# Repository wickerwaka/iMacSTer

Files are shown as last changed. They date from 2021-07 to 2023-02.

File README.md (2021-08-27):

# iMacSTer
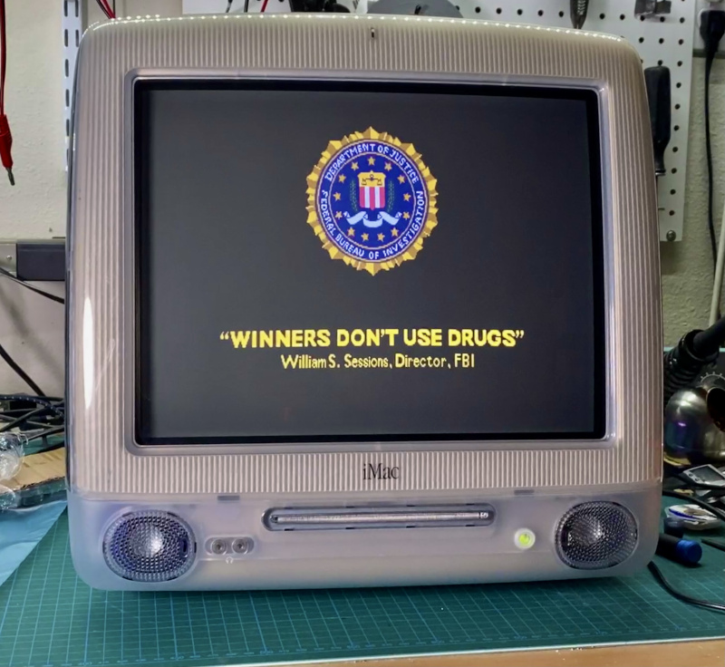
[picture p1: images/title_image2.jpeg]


The iMacSTer is an early 2000's Apple iMac G3 with a MiSTer FPGA multisystem emulator inside of it. It is intended to be a non-destructive modification so the iMac can be returned to it's original state if desired. The mainboard, drives and IO panel are removed and replace by custom hardware, but no cuts are made to the chassis and the new hardware connects to existing internal connections without the need for any soldering. That being said, I can make no guarantees about the long term implications of these modifications. The speakers are being driven by a different amplifier than they were intended for, the new hardware only uses the 5V output from a power supply which is expecting load on the 3.3V and 12V lines also, the monitor is being driven at a resolution higher than it was intended for, heat generation and dissipation characteristics have changed, etc, etc.

## Past Work
None of this would be possible without the work of Rocky Hill and others to reverse engineer the iMac internals and design custom hardware and software to interface with it. I would not have attempted this project if the [imac_g3_ivad_board_init](https://github.com/qbancoffee/imac_g3_ivad_board_init) project did not exist. My PCBs and software is all based on that work and I still use the down converter adaptor board from that project because there was no need to change it.

I also used the IO shield designs that @Diepzeevogel created as part of their [replacement parts project](https://github.com/Diepzeevogel/iMac-G3-replacement-parts) as the basis for my own IO shield. The fit and quality that they were able to achieve is beyond my own skills.

## Features
 * 2W x 2 Stereo amplifier
 * Dual headphone ports for two player fun
 * External volume control
 * 4 external USB ports
 * Built-in WiFi
 * Access to all MiSTer buttons and OSD
 * Sleek design for any modern home

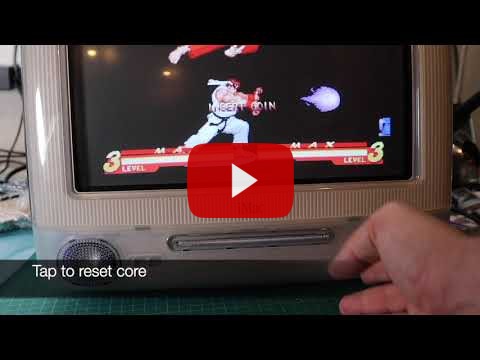
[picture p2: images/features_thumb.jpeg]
Features Video (https://www.youtube.com/watch?v=8O5fEVcCo0Q)


[Other Random Photos](https://photos.app.goo.gl/XmcNqWLyWzHymW5z9)

## Assembly
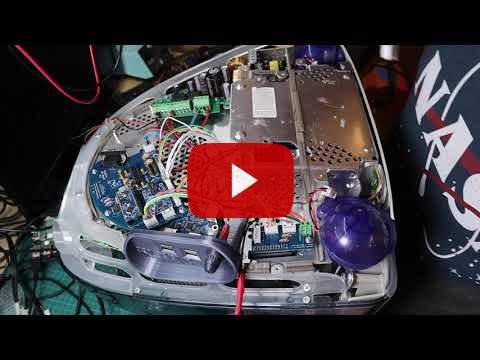
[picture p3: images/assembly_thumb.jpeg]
Assembly Video (https://www.youtube.com/watch?v=OmDPnWWWzPM)


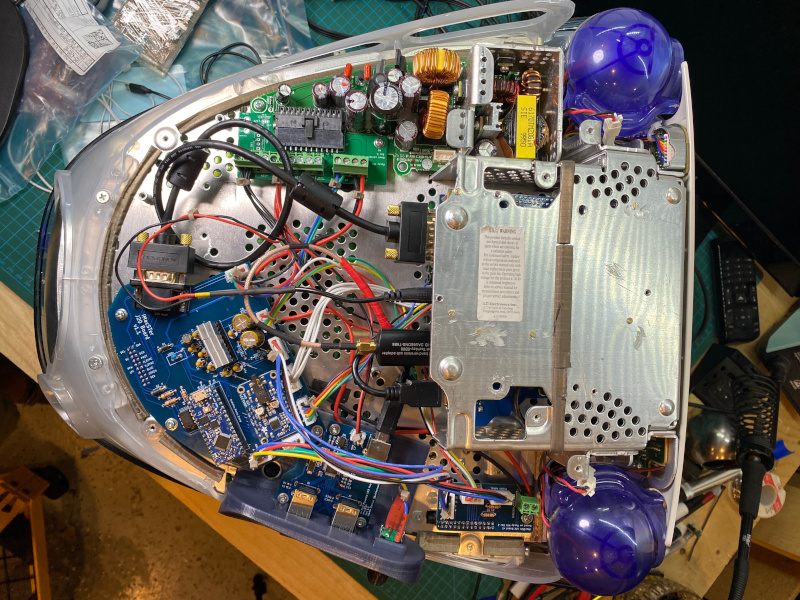
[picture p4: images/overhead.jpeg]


## Main Board
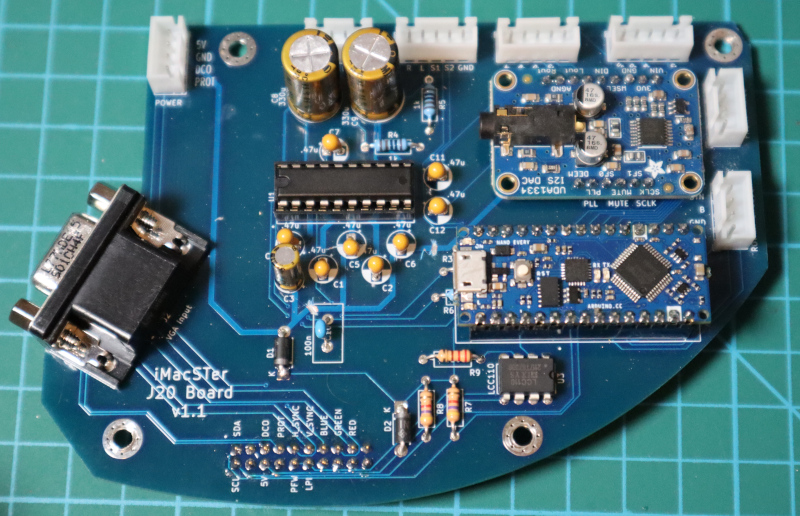
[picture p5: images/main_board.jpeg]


The main board controls the whole system. It contains an I2S digital-to-analog audio converter, an audio amplifier and an Arduino Nano Every for controlling everything. It connects to the J20 connector inside the iMac which provides 5V to the microcontroller even when the system is powered down. The J20 port is also where the VGA signals are from the VGA connector on the board.

The amplifier is a Texas Instruments [TPA6021A4](https://www.ti.com/lit/ds/symlink/tpa6021a4.pdf) 2W Stereo amplifier. I picked this one because it was in the power range I needed, it supported a headphone mode, the volume level could be controlled by a microcontroller and it came in a through-hole package. That last point really limits the options since most amplifier ICs with similar features come in surface mount packages. When I started this project I had no experience designing PCBs or using surface mount components, so I was limiting myself to through-hole parts. The decoupling, biasing and filtering capacitors in the amplifier section are all directly copied from the reference schematics in the datasheet, with the exception of the output capacitors which I switch from 330uF to 2200uF in order to get more bass.

The amplifier output is connected to the speakers and headphones via two JST connectors. The iMac has two separate headphone ports on the front and each has their own headphone sense signal. These signals need to be OR'd together to determine whether the amplifier should be in single ended (headphone) mode or not. This is done by the arduino rather than a separate IC, which has the added advantage of allowing separate volume settings for speaker and headphone mode.

The audio input to the amplifier comes from the [UDA1334A](https://cdn-shop.adafruit.com/product-files/3678/UDA1334ATS.pdf) [breakout board](https://www.adafruit.com/product/3678) from Adafruit. The UDA1334A decodes the I2S audio data from the MiSTer and converts it to an analog signal. I had assumed the output capacitors on the breakout board would block DC into the amplifier so an earlier version of the board did not have any capacitors protecting the input. That assumption cost me a pair of speakers, they literally ripped themselves apart.

The arduino controls the system power, the CRT configuration, the amplifier, the buttons and LEDs on the case and the three standard buttons on the MiSTer. I considered using an ATmega microcontroller directly instead of the Nano Every, however the Nano packs a lot of features into a small space. I want the convenience of a USB port without having to worry about whether I've hooked it all up correctly. 

iMac video hardware requires a special initialization sequence to be sent via I2C before it will power on the CRT and start displaying an image ([much more detailed explaination here](https://github.com/qbancoffee/imac_g3_ivad_board_init/wiki/Convert-and-iMac-G3-slot-loader-into-a-standard-VGA-monitor)). The I2C connection is also used to configure display properties like brightness and alignment. These settings are stored in EEPROM and can be modified using serial commands.

## USB Hubs
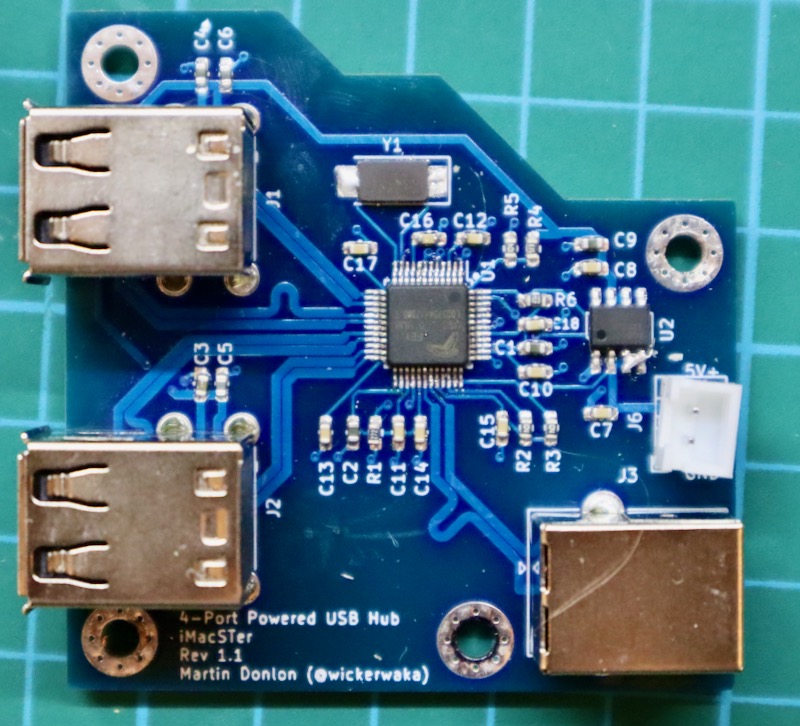
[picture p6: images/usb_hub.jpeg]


There are two USB hubs inside, one is used for internal connections and one is mounted on the IO shield for external connections. The hub is based on the [FE1.1](https://elinux.org/images/e/ee/FE11-datasheet.pdf) chip which does pretty much everything. Building my own USB hubs is not something I considered doing at the start of this project, I had never designed a PCB and I had never used surface mount components. I had deliberately avoided surface mount components when picking an amplifier for the main board. This seemed achievable though and I had watched enough videos at this point to not be terrified of surface mount soldering. It was pretty surprising when it worked!

The hub includes a current-limited switch, but I have not been able to get the power control from the FE1.1 to work correctly. For now it is latched one with a blob of solder. There is still some current limiting due to the thermal shutoff building into the switch, but it is not going to be reported to the hub correctly.

## MiSTer
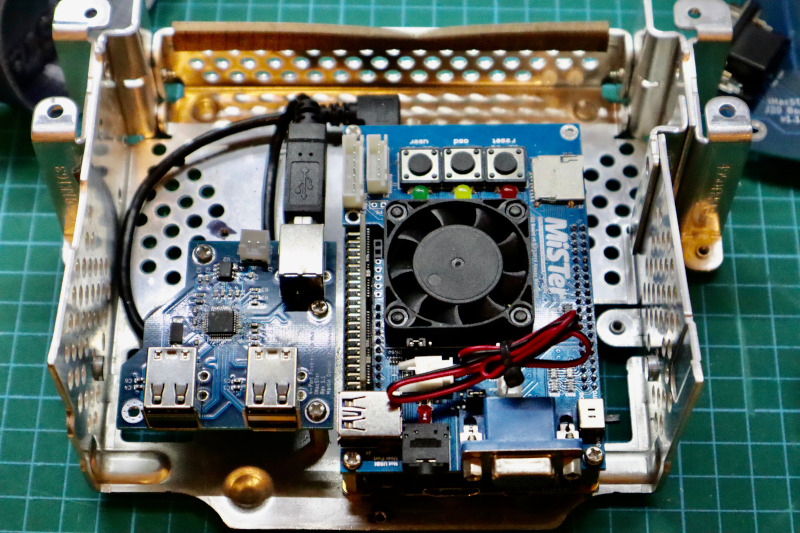
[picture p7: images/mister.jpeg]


The [MiSTer](https://github.com/MiSTer-devel/Main_MiSTer/wiki) setup is the standard combo of DE-10 Nano, 128MB SDRAM and the analog IO board. The 5-pin button and I2S headers are connected to the matching headers on the main board. The MiSTer is mounted in the drive bay alongside one of the USB hubs. I drilled and tapped holes in the drive bay to allow both of them to be mounted. This is a destructive modification, though it is not externally visible and does not impact the functionality of the drive bay if the original drives ever needed to be added back in.

## Power and Front Panel
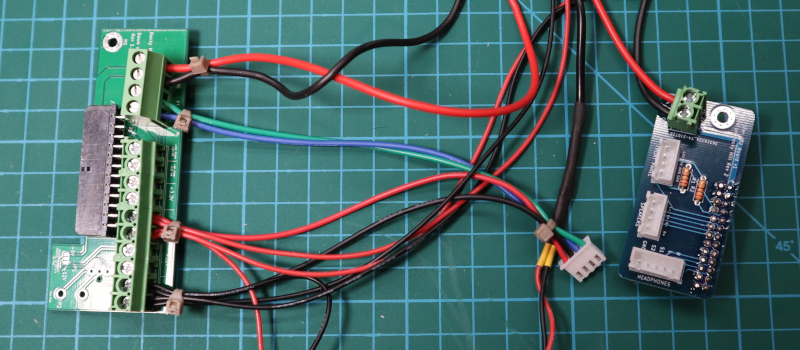
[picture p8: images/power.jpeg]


The power for the system comes from the J22 connector as 24VAC. This 24VAC is feed into the down converter board which outputs 12V, 5V and 3.3V DC. The 5V output is used to power everything else in the system. The J22 connector also has connections for the speakers, headphones, power button and it's LEDs. This are all exposed through three JST connectors on the adaptor board.

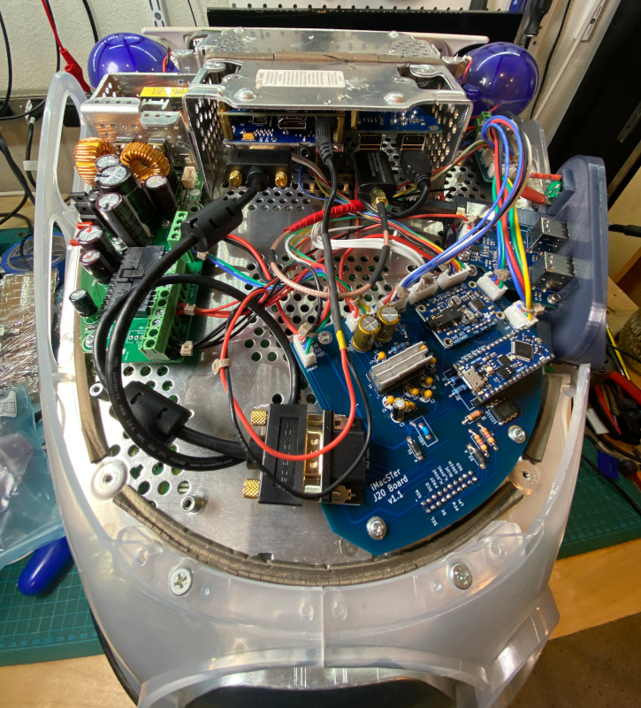
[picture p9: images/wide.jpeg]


## IO Shield
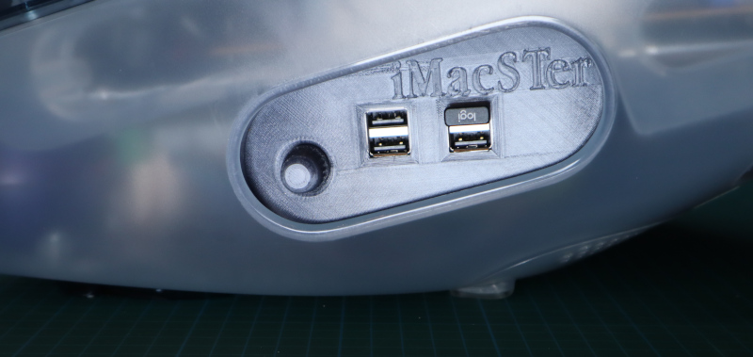
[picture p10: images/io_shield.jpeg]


The IO shield provides a mounting point for the external USB hub and the rotary encoder. Thanks to the work [here](https://github.com/Diepzeevogel/iMac-G3-replacement-parts) it matches the curves of the case very closely. It is 3D printed using eSUN's Semi-transparent Gray PETG filament which matches well with the "Graphite" color of this iMac.

The metal plate that the IO shield is attached to has a lot of holes so finding suitable attachment points was not difficult. However getting access to the other side of that metal plate is extremely difficult so I opted to build in some plugs that expand when a bolt is screwed into them, similar to dry wall screws. 

## Video Modes
The CRT in the iMac is limited to a horizontal sync of 57-63KHz. The only mode suitable for 60Hz refresh rate is 1280x960. At this resolution the horizontal refresh rate is 1000x the vertical rate so when using `vsync_adjust` the vertical rate can be adjusted from 57-63Hz, which gives good coverage for NTSC and most arcade systems. The brightness and alignment of the screen does change across that frequency range, so at the extremes the picture will be slightly distorted. A future version of the board may sample the hsync signal and adjust the video settings based on it.

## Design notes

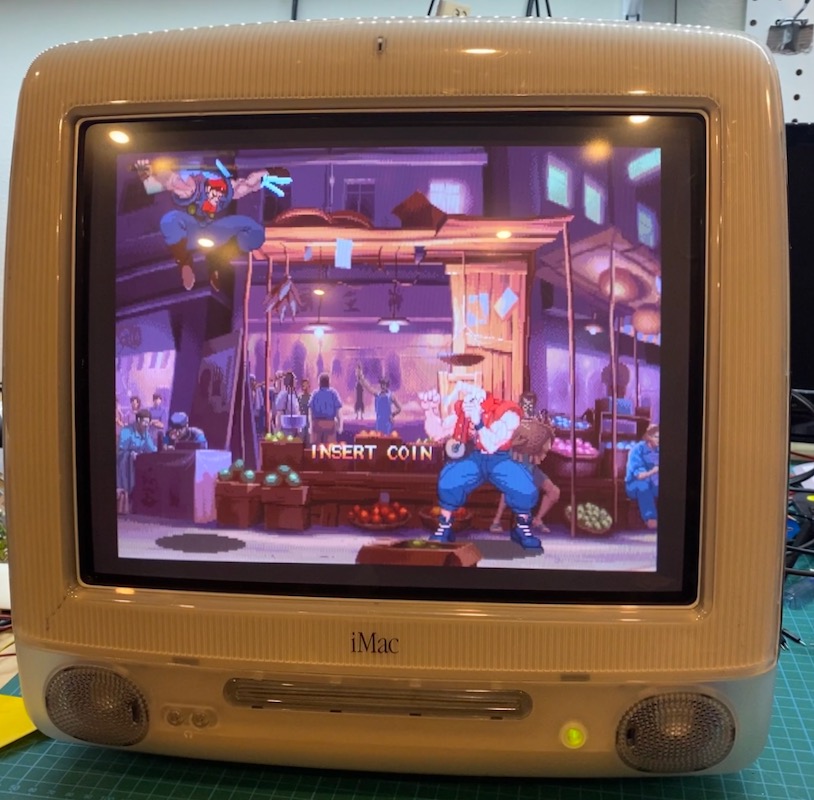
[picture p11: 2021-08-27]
images/title_image.jpeg

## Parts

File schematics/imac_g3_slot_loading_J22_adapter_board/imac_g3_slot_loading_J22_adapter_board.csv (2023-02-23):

Source: | C:\Users\Martin\Source\iMacSTer\schematics\imac_g3_slot_loading_J22_adapter_board\imac_g3_slot_loading_J22_adapter_board.kicad_sch
Date: | 2/22/2023 10:14:35 PM
Tool: | Eeschema (6.0.5)
Generator: | C:\Program Files\KiCad\6.0\bin\scripting\plugins/bom_csv_grouped_by_value.py
Component Count: | 8
Individual Components:
Item | Qty | Reference(s) | Value | LibPart | Footprint | Datasheet | Part# | Vendor
 |  | H1 | MountingHole_Pad | Mechanical:MountingHole_Pad | MountingHole:MountingHole_3.5mm_Pad_Via | ~
 |  | J1 | Conn_02x13_Odd_Even | Connector_Generic:Conn_02x13_Odd_Even | Connector_PinHeader_2.54mm:PinHeader_2x13_P2.54mm_Vertical | https://cdn.amphenol-icc.com/media/wysiwyg/files/drawing/67996.pdf | 3M156308-26-ND | digikey
 |  | J2 | AC Power | Connector:Screw_Terminal_01x02 | TerminalBlock_Phoenix:TerminalBlock_Phoenix_PT-1,5-2-5.0-H_1x02_P5.00mm_Horizontal | https://www.phoenixcontact.com/pxc-oc-itemdetail-pdf-web/eshop?lineItemType=LineItem&UID=1935857 | 277-6405-ND | digikey
 |  | J3 | Conn_01x04_Male | Connector:Conn_01x04_Male | Connector_JST:JST_XH_B4B-XH-A_1x04_P2.50mm_Vertical | ~ | 455-2249-ND | digikey
 |  | J4 | Conn_01x04_Male | Connector:Conn_01x04_Male | Connector_JST:JST_XH_B4B-XH-A_1x04_P2.50mm_Vertical | ~ | 455-2249-ND | digikey
 |  | J5 | Conn_01x04_Male | Connector:Conn_01x05_Male | Connector_JST:JST_XH_B5B-XH-A_1x05_P2.50mm_Vertical | ~ | 455-2270-ND | digikey
 |  | R1 | 220 | Device:R_Small_US | Resistor_THT:R_Axial_DIN0207_L6.3mm_D2.5mm_P7.62mm_Horizontal | https://www.seielect.com/catalog/sei-cf_cfm.pdf | CF14JT220RCT-ND | digikey
 |  | R2 | 220 | Device:R_Small_US | Resistor_THT:R_Axial_DIN0207_L6.3mm_D2.5mm_P7.62mm_Horizontal | https://www.seielect.com/catalog/sei-cf_cfm.pdf | CF14JT220RCT-ND | digikey
Collated Components:
Item | Qty | Reference(s) | Value | LibPart | Footprint | Datasheet | Part# | Vendor
1 | 1 | H1 | MountingHole_Pad | Mechanical:MountingHole_Pad | MountingHole:MountingHole_3.5mm_Pad_Via | ~
2 | 1 | J1 | Conn_02x13_Odd_Even | Connector_Generic:Conn_02x13_Odd_Even | Connector_PinHeader_2.54mm:PinHeader_2x13_P2.54mm_Vertical | https://cdn.amphenol-icc.com/media/wysiwyg/files/drawing/67996.pdf | 3M156308-26-ND | digikey
3 | 1 | J2 | AC Power | Connector:Screw_Terminal_01x02 | TerminalBlock_Phoenix:TerminalBlock_Phoenix_PT-1,5-2-5.0-H_1x02_P5.00mm_Horizontal | https://www.phoenixcontact.com/pxc-oc-itemdetail-pdf-web/eshop?lineItemType=LineItem&UID=1935857 | 277-6405-ND | digikey
4 | 2 | J3, J4 | Conn_01x04_Male | Connector:Conn_01x04_Male | Connector_JST:JST_XH_B4B-XH-A_1x04_P2.50mm_Vertical | ~ | 455-2249-ND | digikey
5 | 1 | J5 | Conn_01x04_Male | Connector:Conn_01x05_Male | Connector_JST:JST_XH_B5B-XH-A_1x05_P2.50mm_Vertical | ~ | 455-2270-ND | digikey
6 | 2 | R1, R2 | 220 | Device:R_Small_US | Resistor_THT:R_Axial_DIN0207_L6.3mm_D2.5mm_P7.62mm_Horizontal | https://www.seielect.com/catalog/sei-cf_cfm.pdf | CF14JT220RCT-ND | digikey

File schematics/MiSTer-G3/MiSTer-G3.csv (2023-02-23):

Source: | C:\Users\Martin\Source\iMacSTer\schematics\MiSTer-G3\MiSTer-G3.kicad_sch
Date: | 2/22/2023 10:15:50 PM
Tool: | Eeschema (6.0.5)
Generator: | C:\Program Files\KiCad\6.0\bin\scripting\plugins/bom_csv_grouped_by_value.py
Component Count: | 42
Individual Components:
Item | Qty | Reference(s) | Value | LibPart | Footprint | Datasheet | Part# | Vendor
 |  | A1 | Arduino_Nano_Every | MCU_Module:Arduino_Nano_Every | Module:Arduino_Nano | https://content.arduino.cc/assets/NANOEveryV3.0_sch.pdf | S7013-ND | digikey
 |  | C1 | .47u | MiSTer-G3-rescue:CP1-Device | Capacitor_THT:CP_Radial_D5.0mm_P2.50mm |  | 478-8779-1-ND | digikey
 |  | C2 | .47u | MiSTer-G3-rescue:CP1-Device | Capacitor_THT:CP_Radial_D5.0mm_P2.50mm |  | 478-8779-1-ND | digikey
 |  | C3 | 10u | MiSTer-G3-rescue:CP1-Device | Capacitor_THT:CP_Radial_D5.0mm_P2.00mm |  | 493-15134-ND | digikey
 |  | C4 | .47u | MiSTer-G3-rescue:CP1-Device | Capacitor_THT:CP_Radial_D5.0mm_P2.50mm |  | 478-8779-1-ND | digikey
 |  | C5 | .47u | MiSTer-G3-rescue:CP1-Device | Capacitor_THT:CP_Radial_D5.0mm_P2.50mm |  | 478-8779-1-ND | digikey
 |  | C6 | .47u | MiSTer-G3-rescue:CP1-Device | Capacitor_THT:CP_Radial_D5.0mm_P2.50mm |  | 478-8779-1-ND | digikey
 |  | C7 | .47u | MiSTer-G3-rescue:CP1-Device | Capacitor_THT:CP_Radial_D5.0mm_P2.50mm |  | 478-8779-1-ND | digikey
 |  | C8 | 330u | MiSTer-G3-rescue:CP1-Device | Capacitor_THT:CP_Radial_D10.0mm_P5.00mm |  | 493-3180-ND | digikey
 |  | C9 | 330u | MiSTer-G3-rescue:CP1-Device | Capacitor_THT:CP_Radial_D10.0mm_P5.00mm |  | 493-3180-ND | digikey
 |  | C10 | 100n | Device:C_Small | Capacitor_THT:C_Disc_D10.5mm_W5.0mm_P5.00mm | ~ | 445-173588-1-ND | digikey
 |  | C11 | .47u | MiSTer-G3-rescue:CP1-Device | Capacitor_THT:CP_Radial_D5.0mm_P2.00mm |  | 478-8779-1-ND | digikey
 |  | C12 | .47u | MiSTer-G3-rescue:CP1-Device | Capacitor_THT:CP_Radial_D5.0mm_P2.00mm |  | 478-8779-1-ND | digikey
 |  | D1 | D_Schottky_ALT | MiSTer-G3-rescue:D_Schottky_ALT-Device | Diode_THT:D_DO-41_SOD81_P7.62mm_Horizontal |  | 1N5819-E3/54GICT-ND | digikey
 |  | D2 | D_Schottky_ALT | MiSTer-G3-rescue:D_Schottky_ALT-Device | Diode_THT:D_DO-41_SOD81_P7.62mm_Horizontal |  | 1N5819-E3/54GICT-ND | digikey
 |  | H1 | MountingHole_Pad | Mechanical:MountingHole_Pad | MountingHole:MountingHole_3.5mm_Pad_Via | ~
 |  | H2 | MountingHole_Pad | Mechanical:MountingHole_Pad | MountingHole:MountingHole_3.5mm_Pad_Via | ~
 |  | H3 | MountingHole_Pad | Mechanical:MountingHole_Pad | MountingHole:MountingHole_3.5mm_Pad_Via | ~
 |  | H4 | MountingHole_Pad | Mechanical:MountingHole_Pad | MountingHole:MountingHole_3.5mm_Pad_Via | ~
 |  | J1 | Apple J20 | Connector_Generic:Conn_02x10_Odd_Even | Connector_PinHeader_2.54mm:PinHeader_2x10_P2.54mm_Vertical | ~ | SAM1068-10-ND | digikey
 |  | J2 | VGA Input | Connector:DB15_Female_HighDensity | Connector_Dsub:DSUB-15-HD_Female_Horizontal_P2.29x1.98mm_EdgePinOffset8.35mm_Housed_MountingHolesOffset10.89mm | ~ | L77HDE15SD1CH4F-ND | digikey
 |  | J3 | Speaker | Connector:Conn_01x04_Male | Connector_JST:JST_XH_B4B-XH-A_1x04_P2.50mm_Vertical | ~ | 455-2249-ND | digikey
 |  | J4 | I2S | Connector:Conn_01x05_Male | Connector_JST:JST_XH_B5B-XH-A_1x05_P2.50mm_Vertical | ~ | 455-2270-ND | digikey
 |  | J5 | Power | Connector:Conn_01x04_Male | Connector_JST:JST_XH_B4B-XH-A_1x04_P2.50mm_Vertical | ~ | 455-2249-ND | digikey
 |  | J6 | Rotary Encoder | Connector:Conn_01x04_Male | Connector_JST:JST_XH_B4B-XH-A_1x04_P2.50mm_Vertical | ~ | 455-2249-ND | digikey
 |  | J7 | Headphones | Connector:Conn_01x05_Male | Connector_JST:JST_XH_B5B-XH-A_1x05_P2.50mm_Vertical | ~ | 455-2270-ND | digikey
 |  | J8 | Front Panel | Connector:Conn_01x04_Male | Connector_JST:JST_XH_B4B-XH-A_1x04_P2.50mm_Vertical | ~ | 455-2249-ND | digikey
 |  | J9 | Buttons | Connector:Conn_01x05_Male | Connector_JST:JST_XH_B5B-XH-A_1x05_P2.50mm_Vertical | ~ | 455-2270-ND | digikey
 |  | R1 | 100k | Device:R | Resistor_THT:R_Axial_DIN0207_L6.3mm_D2.5mm_P10.16mm_Horizontal | ~ | 100KQBK-ND | digikey
 |  | R2 | 100k | Device:R | Resistor_THT:R_Axial_DIN0207_L6.3mm_D2.5mm_P10.16mm_Horizontal | ~ | 100KQBK-ND | digikey
 |  | R3 | 10k | Device:R | Resistor_THT:R_Axial_DIN0207_L6.3mm_D2.5mm_P10.16mm_Horizontal | ~ | 10KQBK-ND | digikey
 |  | R4 | 1k | Device:R | Resistor_THT:R_Axial_DIN0207_L6.3mm_D2.5mm_P10.16mm_Horizontal | ~ | 1.0KQBK-ND | digikey
 |  | R5 | 1k | Device:R | Resistor_THT:R_Axial_DIN0207_L6.3mm_D2.5mm_P10.16mm_Horizontal | ~ | 1.0KQBK-ND | digikey
 |  | R6 | 10k | Device:R_Small | Resistor_THT:R_Axial_DIN0207_L6.3mm_D2.5mm_P10.16mm_Horizontal | ~ | 10KQBK-ND | digikey
 |  | R7 | 4.7k | Device:R_Small | Resistor_THT:R_Axial_DIN0207_L6.3mm_D2.5mm_P10.16mm_Horizontal | ~ | 4.7KQBK-ND | digikey
 |  | R8 | 4.7k | Device:R_Small | Resistor_THT:R_Axial_DIN0207_L6.3mm_D2.5mm_P10.16mm_Horizontal | ~ | 4.7KQBK-ND | digikey
 |  | R9 | 220 | Device:R_Small | Resistor_THT:R_Axial_DIN0207_L6.3mm_D2.5mm_P10.16mm_Horizontal | ~ | 220QBK-ND | digikey
 |  | R10 | 100k | Device:R | Resistor_THT:R_Axial_DIN0207_L6.3mm_D2.5mm_P10.16mm_Horizontal | ~ | 100KQBK-ND | digikey
 |  | R11 | 100k | Device:R | Resistor_THT:R_Axial_DIN0207_L6.3mm_D2.5mm_P10.16mm_Horizontal | ~ | 100KQBK-ND | digikey
 |  | U1 | TPA6021A4N | MiSTer-Custom:TPA6021A4N | MiSTer-G3:TPA6021A4 |  | 296-18249-5-ND | digikey
 |  | U2 | UDA1334A | MiSTer-Custom:UDA1334A | MiSTer-G3:UDA1334_Breakout |  | 3678 | adafruit
 |  | U3 | LCC110 | Relay_SolidState:LCC110 | Package_DIP:DIP-8_W7.62mm | http://www.ixysic.com/home/pdfs.nsf/www/LCC110.pdf/$file/LCC110.pdf | CLA106-ND | digikey
Collated Components:
Item | Qty | Reference(s) | Value | LibPart | Footprint | Datasheet | Part# | Vendor
1 | 1 | A1 | Arduino_Nano_Every | MCU_Module:Arduino_Nano_Every | Module:Arduino_Nano | https://content.arduino.cc/assets/NANOEveryV3.0_sch.pdf | S7013-ND | digikey
2 | 6 | C1, C2, C4, C5, C6, C7 | .47u | MiSTer-G3-rescue:CP1-Device | Capacitor_THT:CP_Radial_D5.0mm_P2.50mm |  | 478-8779-1-ND | digikey
3 | 1 | C3 | 10u | MiSTer-G3-rescue:CP1-Device | Capacitor_THT:CP_Radial_D5.0mm_P2.00mm |  | 493-15134-ND | digikey
4 | 2 | C8, C9 | 330u | MiSTer-G3-rescue:CP1-Device | Capacitor_THT:CP_Radial_D10.0mm_P5.00mm |  | 493-3180-ND | digikey
5 | 1 | C10 | 100n | Device:C_Small | Capacitor_THT:C_Disc_D10.5mm_W5.0mm_P5.00mm | ~ | 445-173588-1-ND | digikey
6 | 2 | C11, C12 | .47u | MiSTer-G3-rescue:CP1-Device | Capacitor_THT:CP_Radial_D5.0mm_P2.00mm |  | 478-8779-1-ND | digikey
7 | 2 | D1, D2 | D_Schottky_ALT | MiSTer-G3-rescue:D_Schottky_ALT-Device | Diode_THT:D_DO-41_SOD81_P7.62mm_Horizontal |  | 1N5819-E3/54GICT-ND | digikey
8 | 4 | H1, H2, H3, H4 | MountingHole_Pad | Mechanical:MountingHole_Pad | MountingHole:MountingHole_3.5mm_Pad_Via | ~
9 | 1 | J1 | Apple J20 | Connector_Generic:Conn_02x10_Odd_Even | Connector_PinHeader_2.54mm:PinHeader_2x10_P2.54mm_Vertical | ~ | SAM1068-10-ND | digikey
10 | 1 | J2 | VGA Input | Connector:DB15_Female_HighDensity | Connector_Dsub:DSUB-15-HD_Female_Horizontal_P2.29x1.98mm_EdgePinOffset8.35mm_Housed_MountingHolesOffset10.89mm | ~ | L77HDE15SD1CH4F-ND | digikey
11 | 1 | J3 | Speaker | Connector:Conn_01x04_Male | Connector_JST:JST_XH_B4B-XH-A_1x04_P2.50mm_Vertical | ~ | 455-2249-ND | digikey
12 | 1 | J4 | I2S | Connector:Conn_01x05_Male | Connector_JST:JST_XH_B5B-XH-A_1x05_P2.50mm_Vertical | ~ | 455-2270-ND | digikey
13 | 1 | J5 | Power | Connector:Conn_01x04_Male | Connector_JST:JST_XH_B4B-XH-A_1x04_P2.50mm_Vertical | ~ | 455-2249-ND | digikey
14 | 1 | J6 | Rotary Encoder | Connector:Conn_01x04_Male | Connector_JST:JST_XH_B4B-XH-A_1x04_P2.50mm_Vertical | ~ | 455-2249-ND | digikey
15 | 1 | J7 | Headphones | Connector:Conn_01x05_Male | Connector_JST:JST_XH_B5B-XH-A_1x05_P2.50mm_Vertical | ~ | 455-2270-ND | digikey
16 | 1 | J8 | Front Panel | Connector:Conn_01x04_Male | Connector_JST:JST_XH_B4B-XH-A_1x04_P2.50mm_Vertical | ~ | 455-2249-ND | digikey
17 | 1 | J9 | Buttons | Connector:Conn_01x05_Male | Connector_JST:JST_XH_B5B-XH-A_1x05_P2.50mm_Vertical | ~ | 455-2270-ND | digikey
18 | 4 | R1, R2, R10, R11 | 100k | Device:R | Resistor_THT:R_Axial_DIN0207_L6.3mm_D2.5mm_P10.16mm_Horizontal | ~ | 100KQBK-ND | digikey
19 | 1 | R3 | 10k | Device:R | Resistor_THT:R_Axial_DIN0207_L6.3mm_D2.5mm_P10.16mm_Horizontal | ~ | 10KQBK-ND | digikey
20 | 2 | R4, R5 | 1k | Device:R | Resistor_THT:R_Axial_DIN0207_L6.3mm_D2.5mm_P10.16mm_Horizontal | ~ | 1.0KQBK-ND | digikey
21 | 1 | R6 | 10k | Device:R_Small | Resistor_THT:R_Axial_DIN0207_L6.3mm_D2.5mm_P10.16mm_Horizontal | ~ | 10KQBK-ND | digikey
22 | 2 | R7, R8 | 4.7k | Device:R_Small | Resistor_THT:R_Axial_DIN0207_L6.3mm_D2.5mm_P10.16mm_Horizontal | ~ | 4.7KQBK-ND | digikey
23 | 1 | R9 | 220 | Device:R_Small | Resistor_THT:R_Axial_DIN0207_L6.3mm_D2.5mm_P10.16mm_Horizontal | ~ | 220QBK-ND | digikey
24 | 1 | U1 | TPA6021A4N | MiSTer-Custom:TPA6021A4N | MiSTer-G3:TPA6021A4 |  | 296-18249-5-ND | digikey
25 | 1 | U2 | UDA1334A | MiSTer-Custom:UDA1334A | MiSTer-G3:UDA1334_Breakout |  | 3678 | adafruit
26 | 1 | U3 | LCC110 | Relay_SolidState:LCC110 | Package_DIP:DIP-8_W7.62mm | http://www.ixysic.com/home/pdfs.nsf/www/LCC110.pdf/$file/LCC110.pdf | CLA106-ND | digikey

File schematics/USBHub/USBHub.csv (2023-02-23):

Source: | C:\Users\Martin\Source\iMacSTer\schematics\USBHub\USBHub.kicad_sch
Date: | 2/22/2023 10:15:37 PM
Tool: | Eeschema (6.0.5)
Generator: | C:\Program Files\KiCad\6.0\bin\scripting\plugins/bom_csv_grouped_by_value.py
Component Count: | 35
Individual Components:
Item | Qty | Reference(s) | Value | LibPart | Footprint | Datasheet | Part# | Vendor
 |  | C1 | 10u | Device:C_Small | Capacitor_SMD:C_0603_1608Metric_Pad1.08x0.95mm_HandSolder | ~ | 1276-1038-1-ND | digikey
 |  | C2 | 10u | Device:C_Small | Capacitor_SMD:C_0603_1608Metric_Pad1.08x0.95mm_HandSolder | ~ | 1276-1038-1-ND | digikey
 |  | C3 | 10u | Device:C_Small | Capacitor_SMD:C_0603_1608Metric_Pad1.08x0.95mm_HandSolder | ~ | 1276-1038-1-ND | digikey
 |  | C4 | 10u | Device:C_Small | Capacitor_SMD:C_0603_1608Metric_Pad1.08x0.95mm_HandSolder | ~ | 1276-1038-1-ND | digikey
 |  | C5 | 10u | Device:C_Small | Capacitor_SMD:C_0603_1608Metric_Pad1.08x0.95mm_HandSolder | ~ | 1276-1038-1-ND | digikey
 |  | C6 | 10u | Device:C_Small | Capacitor_SMD:C_0603_1608Metric_Pad1.08x0.95mm_HandSolder | ~ | 1276-1038-1-ND | digikey
 |  | C7 | 100n | Device:C_Small | Capacitor_SMD:C_0603_1608Metric_Pad1.08x0.95mm_HandSolder | ~ | 1276-1935-1-ND | digikey
 |  | C8 | 100n | Device:C_Small | Capacitor_SMD:C_0603_1608Metric_Pad1.08x0.95mm_HandSolder | ~ | 1276-1935-1-ND | digikey
 |  | C9 | 10u | Device:C_Small | Capacitor_SMD:C_0603_1608Metric_Pad1.08x0.95mm_HandSolder | ~ | 1276-1038-1-ND | digikey
 |  | C10 | 100n | Device:C_Small | Capacitor_SMD:C_0603_1608Metric_Pad1.08x0.95mm_HandSolder | ~ | 1276-1935-1-ND | digikey
 |  | C11 | 100n | Device:C_Small | Capacitor_SMD:C_0603_1608Metric_Pad1.08x0.95mm_HandSolder | ~ | 1276-1935-1-ND | digikey
 |  | C12 | 100n | Device:C_Small | Capacitor_SMD:C_0603_1608Metric_Pad1.08x0.95mm_HandSolder | ~ | 1276-1935-1-ND | digikey
 |  | C13 | 100n | Device:C_Small | Capacitor_SMD:C_0603_1608Metric_Pad1.08x0.95mm_HandSolder | ~ | 1276-1935-1-ND | digikey
 |  | C14 | 100n | Device:C_Small | Capacitor_SMD:C_0603_1608Metric_Pad1.08x0.95mm_HandSolder | ~ | 1276-1935-1-ND | digikey
 |  | C15 | 100n | Device:C_Small | Capacitor_SMD:C_0603_1608Metric_Pad1.08x0.95mm_HandSolder | ~ | 1276-1935-1-ND | digikey
 |  | C16 | 100n | Device:C_Small | Capacitor_SMD:C_0603_1608Metric_Pad1.08x0.95mm_HandSolder | ~ | 1276-1935-1-ND | digikey
 |  | C17 | 100n | Device:C_Small | Capacitor_SMD:C_0603_1608Metric_Pad1.08x0.95mm_HandSolder | ~ | 1276-1935-1-ND | digikey
 |  | C18 | 100n | Device:C_Small | Capacitor_SMD:C_0603_1608Metric_Pad1.08x0.95mm_HandSolder | ~ | 1276-1935-1-ND | digikey
 |  | H1 | MountingHole_Pad | Mechanical:MountingHole_Pad | MountingHole:MountingHole_3.2mm_M3_Pad_Via | ~
 |  | H2 | MountingHole_Pad | Mechanical:MountingHole_Pad | MountingHole:MountingHole_3.2mm_M3_Pad_Via | ~
 |  | H3 | MountingHole_Pad | Mechanical:MountingHole_Pad | MountingHole:MountingHole_3.2mm_M3_Pad_Via | ~
 |  | H4 | MountingHole_Pad | Mechanical:MountingHole_Pad | MountingHole:MountingHole_3.2mm_M3_Pad_Via | ~
 |  | J1 | USB_A_STACKED | USBHub:USB_A_STACKED | Connector_USB:USB_A_Wuerth_61400826021_Horizontal_Stacked |  | 2057-USB-A-D-RA-ND | digikey
 |  | J2 | USB_A_STACKED | USBHub:USB_A_STACKED | Connector_USB:USB_A_Wuerth_61400826021_Horizontal_Stacked |  | 2057-USB-A-D-RA-ND | digikey
 |  | J3 | USB_B | Connector:USB_B | Connector_USB:USB_B_OST_USB-B1HSxx_Horizontal | ~ | ED2983-ND | digikey
 |  | J6 | Screw_Terminal_01x02 | Connector:Screw_Terminal_01x02 | TerminalBlock_Phoenix:TerminalBlock_Phoenix_MPT-0,5-2-2.54_1x02_P2.54mm_Horizontal | ~ | 277-1273-ND | digikey
 |  | R1 | 2.7K | Device:R_Small | Resistor_SMD:R_0603_1608Metric_Pad0.98x0.95mm_HandSolder | ~ | 311-2.7KGRCT-ND | digikey
 |  | R2 | 100k | Device:R_Small | Resistor_SMD:R_0603_1608Metric_Pad0.98x0.95mm_HandSolder | ~ | 311-100KGRCT-ND | digikey
 |  | R3 | 100k | Device:R_Small | Resistor_SMD:R_0603_1608Metric_Pad0.98x0.95mm_HandSolder | ~ | 311-100KGRCT-ND | digikey
 |  | R4 | 47k | Device:R_Small | Resistor_SMD:R_0603_1608Metric_Pad0.98x0.95mm_HandSolder | ~ | 311-47KGRCT-ND | digikey
 |  | R5 | 100k | Device:R_Small | Resistor_SMD:R_0603_1608Metric_Pad0.98x0.95mm_HandSolder | ~ | 311-100KGRCT-ND | digikey
 |  | R6 | 10k | Device:R_Small | Resistor_SMD:R_0603_1608Metric_Pad0.98x0.95mm_HandSolder | ~ | 311-10KGRCT-ND | digikey
 |  | U1 | FE1.1 | USBHub:FE1.1 | USBHub:FE1_1_QFP48
 |  | U2 | AP2411 | USBHub:AP2411 | USBHub:AP24x1_SO8_HandSolder |  | AP2411S-13DICT-ND | digikey
 |  | Y1 | 12Mhz | Device:Crystal | Crystal:Crystal_SMD_0603-2Pin_6.0x3.5mm_HandSoldering | ~ | F61200046CT-ND | digikey
Collated Components:
Item | Qty | Reference(s) | Value | LibPart | Footprint | Datasheet | Part# | Vendor
1 | 7 | C1, C2, C3, C4, C5, C6, C9 | 10u | Device:C_Small | Capacitor_SMD:C_0603_1608Metric_Pad1.08x0.95mm_HandSolder | ~ | 1276-1038-1-ND | digikey
2 | 11 | C7, C8, C10, C11, C12, C13, C14, C15, C16, C17, C18 | 100n | Device:C_Small | Capacitor_SMD:C_0603_1608Metric_Pad1.08x0.95mm_HandSolder | ~ | 1276-1935-1-ND | digikey
3 | 4 | H1, H2, H3, H4 | MountingHole_Pad | Mechanical:MountingHole_Pad | MountingHole:MountingHole_3.2mm_M3_Pad_Via | ~
4 | 2 | J1, J2 | USB_A_STACKED | USBHub:USB_A_STACKED | Connector_USB:USB_A_Wuerth_61400826021_Horizontal_Stacked |  | 2057-USB-A-D-RA-ND | digikey
5 | 1 | J3 | USB_B | Connector:USB_B | Connector_USB:USB_B_OST_USB-B1HSxx_Horizontal | ~ | ED2983-ND | digikey
6 | 1 | J6 | Screw_Terminal_01x02 | Connector:Screw_Terminal_01x02 | TerminalBlock_Phoenix:TerminalBlock_Phoenix_MPT-0,5-2-2.54_1x02_P2.54mm_Horizontal | ~ | 277-1273-ND | digikey
7 | 1 | R1 | 2.7K | Device:R_Small | Resistor_SMD:R_0603_1608Metric_Pad0.98x0.95mm_HandSolder | ~ | 311-2.7KGRCT-ND | digikey
8 | 3 | R2, R3, R5 | 100k | Device:R_Small | Resistor_SMD:R_0603_1608Metric_Pad0.98x0.95mm_HandSolder | ~ | 311-100KGRCT-ND | digikey
9 | 1 | R4 | 47k | Device:R_Small | Resistor_SMD:R_0603_1608Metric_Pad0.98x0.95mm_HandSolder | ~ | 311-47KGRCT-ND | digikey
10 | 1 | R6 | 10k | Device:R_Small | Resistor_SMD:R_0603_1608Metric_Pad0.98x0.95mm_HandSolder | ~ | 311-10KGRCT-ND | digikey
11 | 1 | U1 | FE1.1 | USBHub:FE1.1 | USBHub:FE1_1_QFP48
12 | 1 | U2 | AP2411 | USBHub:AP2411 | USBHub:AP24x1_SO8_HandSolder |  | AP2411S-13DICT-ND | digikey
13 | 1 | Y1 | 12Mhz | Device:Crystal | Crystal:Crystal_SMD_0603-2Pin_6.0x3.5mm_HandSoldering | ~ | F61200046CT-ND | digikey

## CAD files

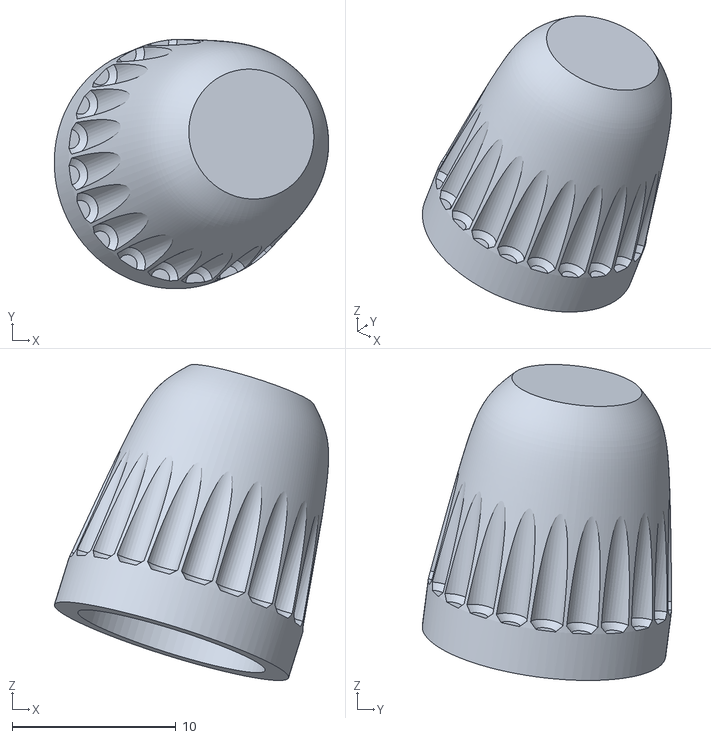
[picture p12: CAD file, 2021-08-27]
models/iMacSTer Volume Knob.stl
16.8 x 15.2 x 19.3

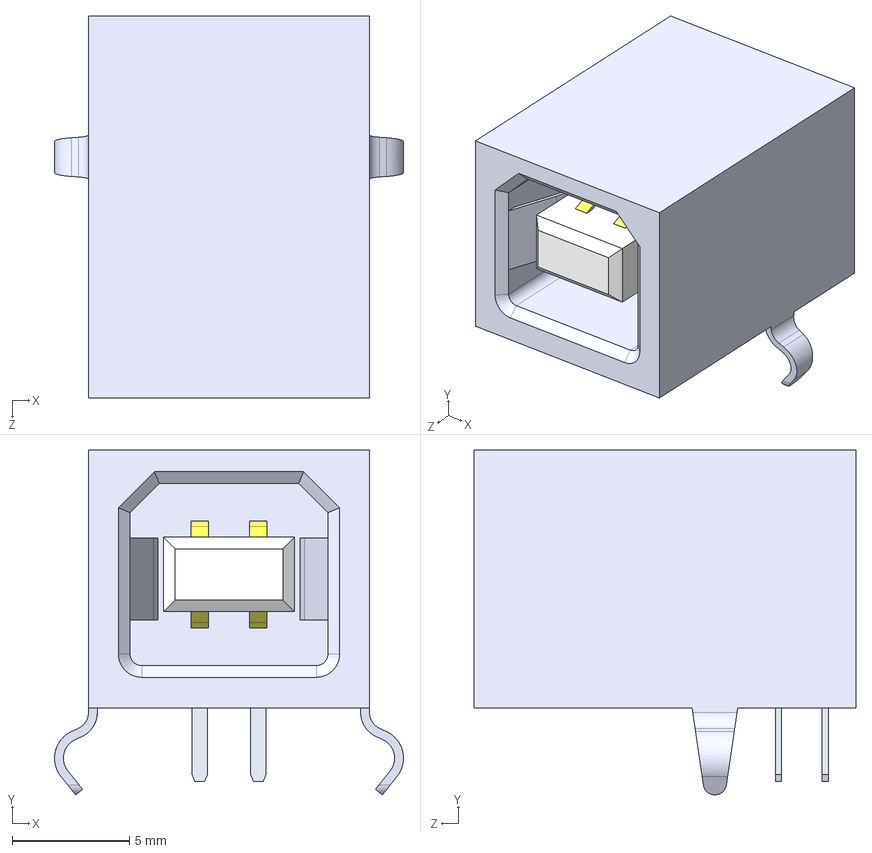
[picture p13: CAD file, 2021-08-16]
schematics/USBHub/CAD/USB-type-B.stp
14.9 x 14.7 x 16.3 mm

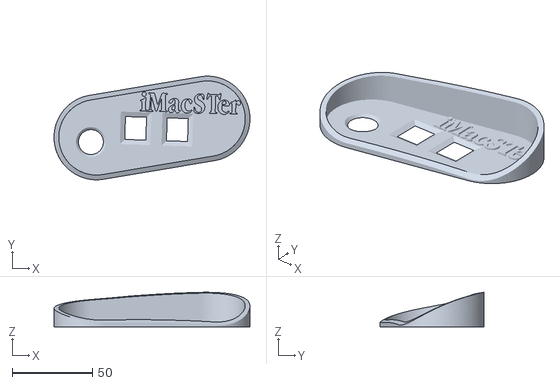
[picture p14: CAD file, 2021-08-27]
models/iMacSTer IO Shield.stl
122.0 x 64.6 x 21.5

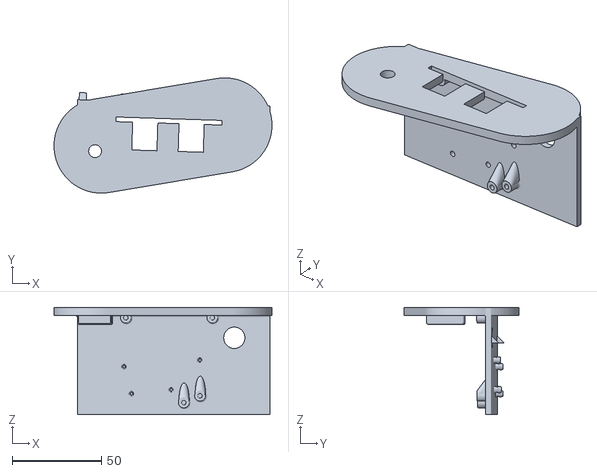
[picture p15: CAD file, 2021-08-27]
models/iMacSTer Mount.stl
122.1 x 64.6 x 60.0

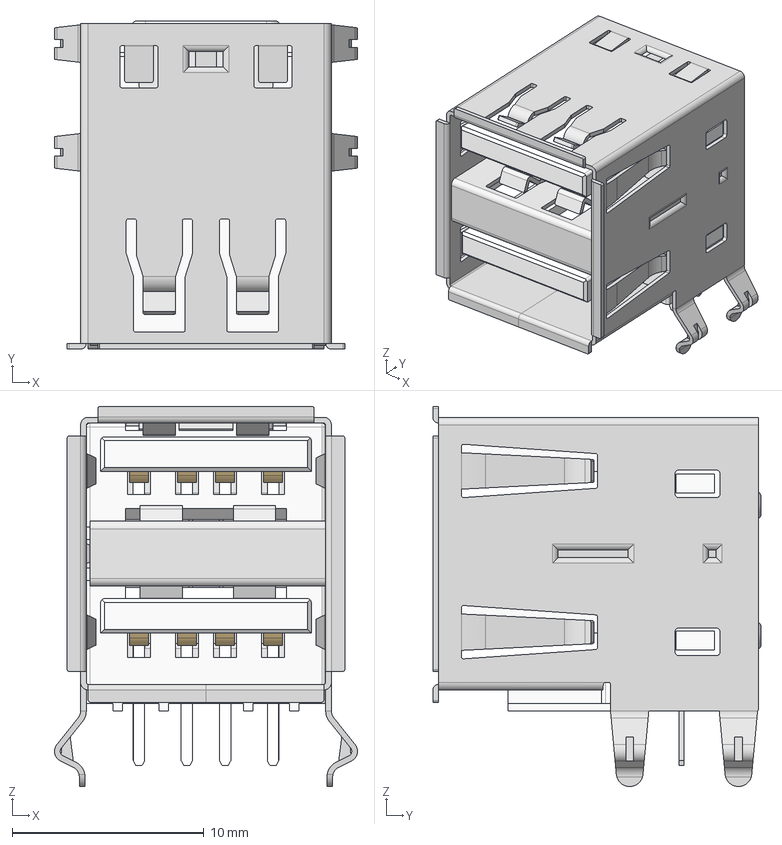
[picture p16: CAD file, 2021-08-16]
schematics/USBHub/CAD/61400826021.stp
15.8 x 17.1 x 19.8 mm
61400826021_Shielding1
61400826021_Housing
61400826021_Shielding2
61400826021_Pin2 x 4
61400826021_Pin1 x 4
61400826021_Shielding3

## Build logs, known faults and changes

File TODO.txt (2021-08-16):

IO Panel with holes for USB ports and rotary encoder.
Print some plastic standoffs
Try different mister placement

DONE
-Test larger speaker blocking caps
-Update code for new pin assignments
-Add button code
-Add blocking capacitors
-Test headphone sense
-Replace screw terminals with JST headers
-Split power header into power and front panel (buttons, LEDS)
-Split audio header into speakers and headphones
-Add JST header for MiSTer buttons
-Add button for rotary encoder

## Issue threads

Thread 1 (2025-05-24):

An issue of issues.

Numbski, 2025-05-24:
Hi!  I just acquired a Ruby iMac G3 with the intent of replicating this project!

You've had yours for a couple of years now, and mentioned that there were some sync issues you ran into that perhaps you might be interested in fixing later.

Have you run into anything else?  The reason I ask is because there were some simple changes I was looking to make to the PCBs anyway.  Wanted to make the rear HD15 usable for analog output, potentially by splitting the HDMI, then use a VGA DAC to that port.  That way direct video could be used.  Also looking at routing HDMI to the side panel, and tying in an esp32 to allow for some level of IoT control.

Figured it would be good to bounce off of you before plowing forward!

wickerwaka, 2025-06-11:
The main issue is that the display has a very limited sync range, it's not multi-sync. So you can't use analog output directly and you can't use the scandoubler. I had to use VGA output with the scaler enabled and the video mode set to 1280x960 @ 60hz. If you wanted to have a usable HD15 output you could get a HDMI->VGA DAC and use the HDMI output to drive the display and then you could use the VGA port on the analog IO port for your output.

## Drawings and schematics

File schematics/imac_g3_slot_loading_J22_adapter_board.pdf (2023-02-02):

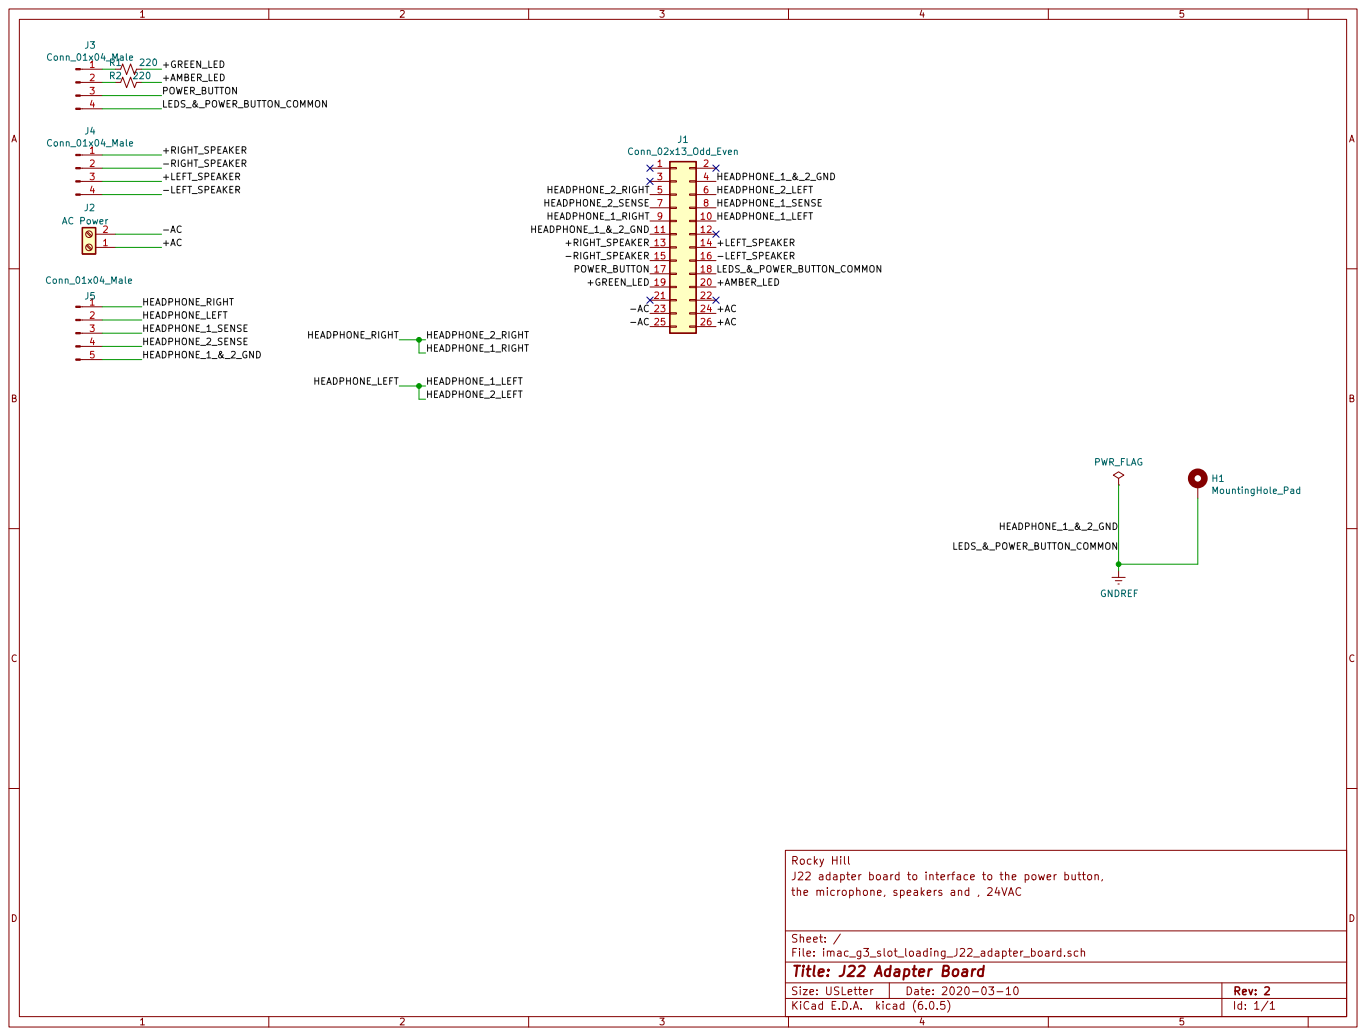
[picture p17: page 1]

J22 adapter board to interface to the power button,
the microphone, speakers and , 24VAC

File: imac_g3_slot_loading_J22_adapter_board.sch Sheet: /
Id: 1/1 Title: J22 Adapter Board

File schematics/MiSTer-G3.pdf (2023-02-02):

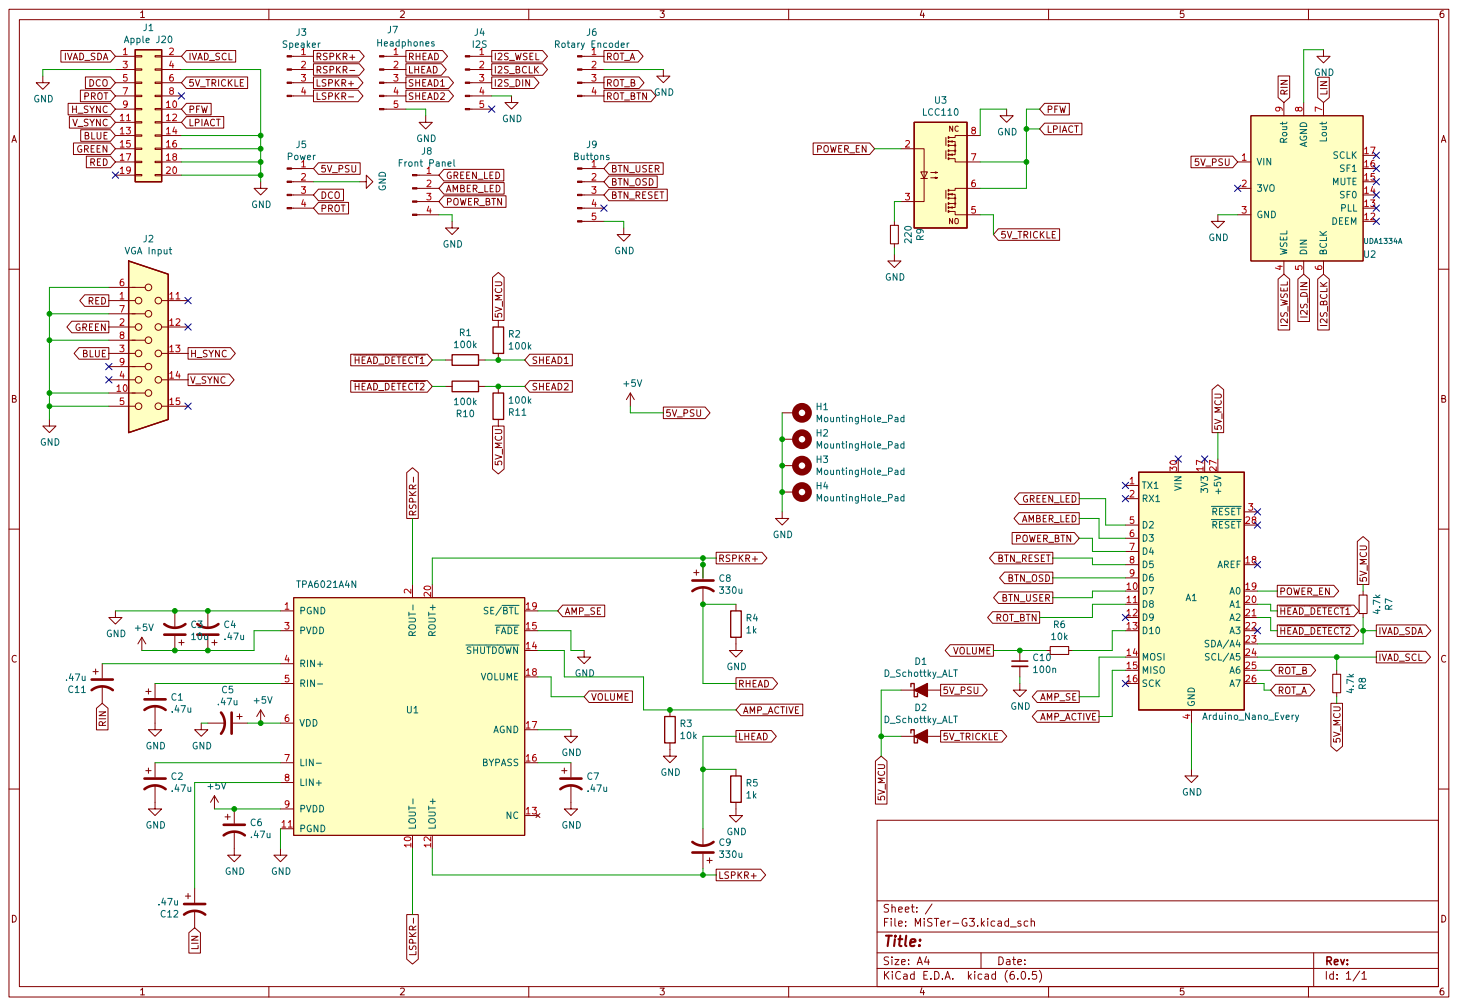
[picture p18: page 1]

File: MiSTer-G3.kicad_sch Sheet: / GND

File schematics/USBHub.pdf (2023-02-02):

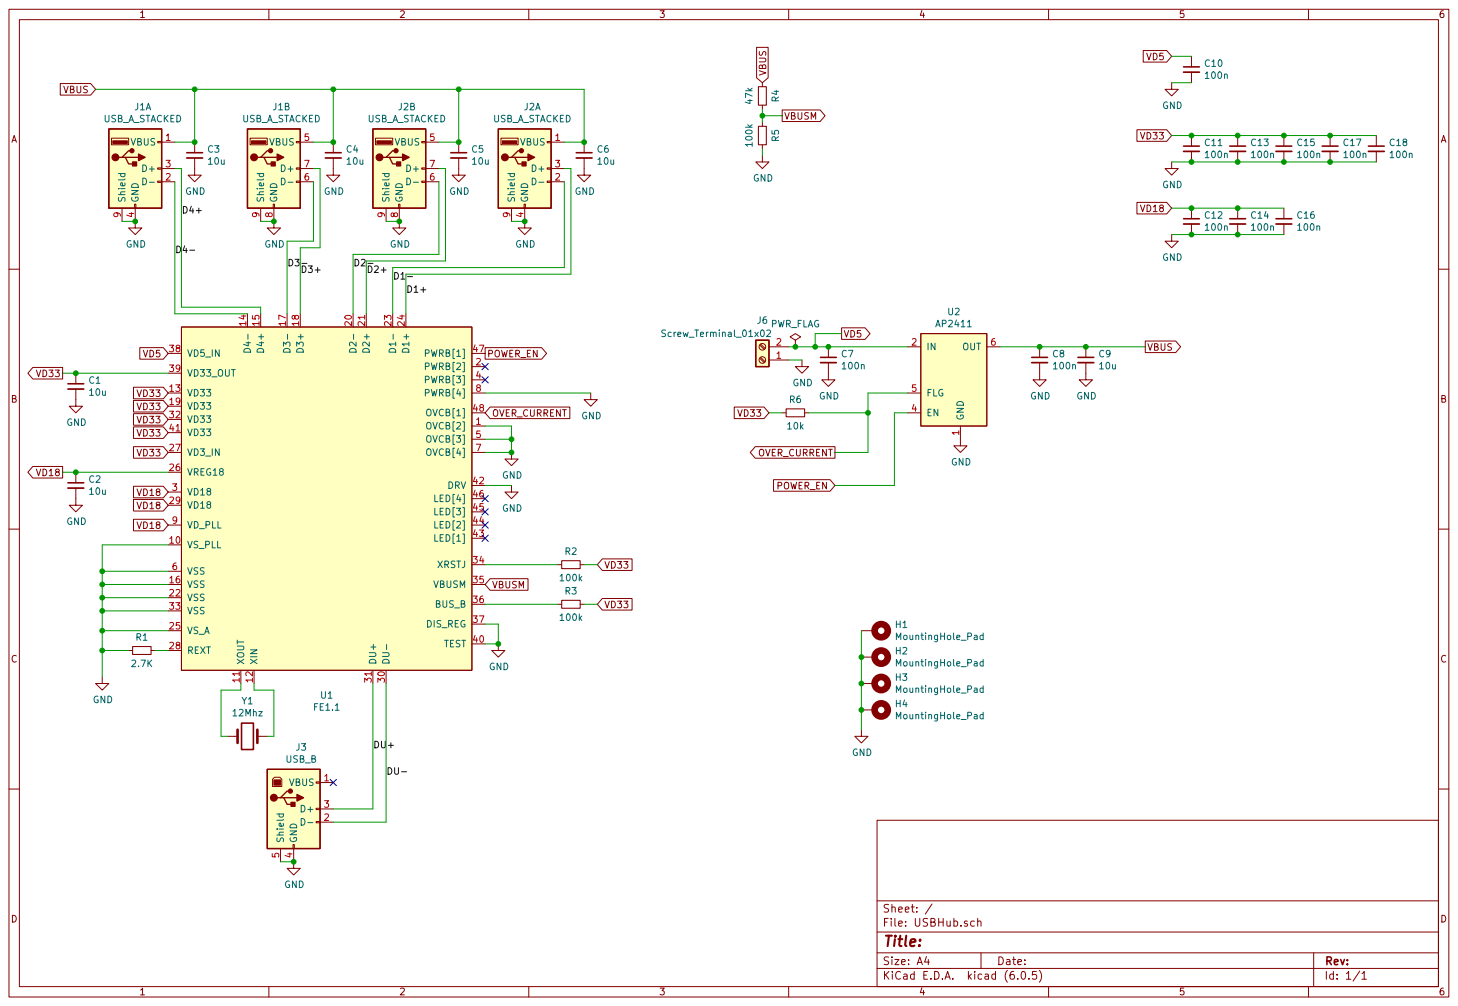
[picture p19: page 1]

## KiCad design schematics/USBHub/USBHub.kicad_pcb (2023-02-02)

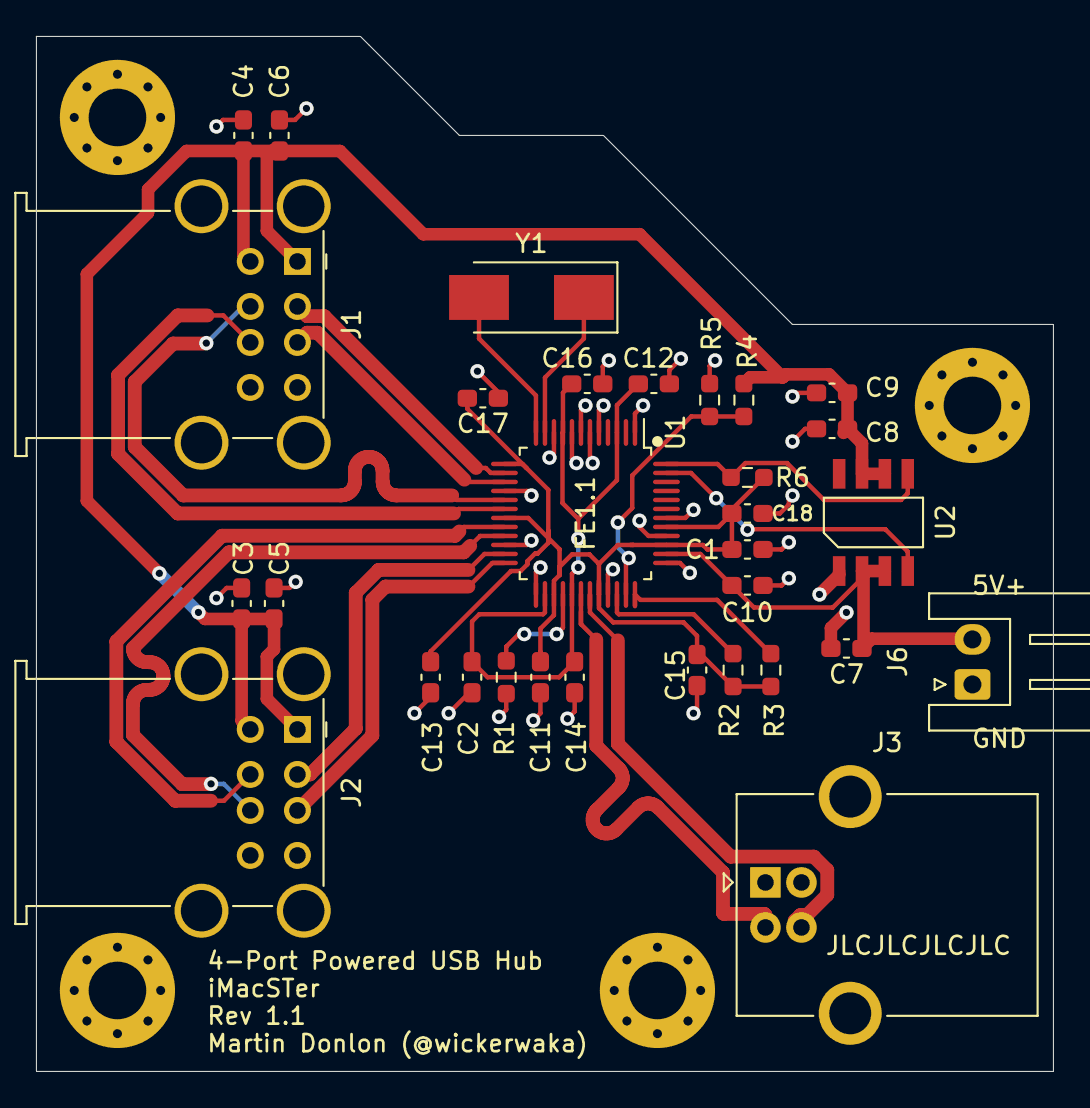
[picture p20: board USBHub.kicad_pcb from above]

Board: 2 copper layers, 56.5 x 57.5 mm, 35 parts (0 on the bottom side), 23 nets.

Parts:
C1, C2, C3, C4, C5, C6, C9: 10u; C_0603_1608Metric_Pad1.08x0.95mm_HandSolder
C7, C8, C10, C11, C12, C13, C14, C15, C16, C17, C18: 100n; C_0603_1608Metric_Pad1.08x0.95mm_HandSolder
H1, H2, H3, H4: MountingHole_Pad; MountingHole_3.2mm_M3_Pad_Via
J1, J2: USB_A_STACKED; USB_A_Wuerth_61400826021_Horizontal_Stacked
J3: USB_B; USB_B_OST_USB-B1HSxx_Horizontal
J6: Screw_Terminal_01x02; JST_XH_S2B-XH-A_1x02_P2.50mm_Horizontal
R1: 2.7K; R_0603_1608Metric_Pad0.98x0.95mm_HandSolder
R2, R3, R5: 100k; R_0603_1608Metric_Pad0.98x0.95mm_HandSolder
R4: 47k; R_0603_1608Metric_Pad0.98x0.95mm_HandSolder
R6: 10k; R_0603_1608Metric_Pad0.98x0.95mm_HandSolder
U1: FE1.1; FE1_1_QFP48
U2: AP2411; AP24x1_SO8_HandSolder
Y1: 12Mhz; Crystal_SMD_0603-2Pin_6.0x3.5mm_HandSoldering

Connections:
/D1+: J2.3, U1.24
/D1-: J2.2, U1.23
/D2+: J2.7, U1.21
/D2-: J2.6, U1.20
/D3+: J1.7, U1.18
/D3-: J1.6, U1.17
/D4+: J1.3, U1.15
/D4-: J1.2, U1.14
/DU+: J3.3, U1.31
/DU-: J3.2, U1.30
GND: C1.2, C2.2, C3.2, C4.2, C5.2, C6.2, C7.2, C8.2, C9.2, C10.2, C11.2, C12.2, C13.2, C14.2, C15.2, C16.2, C17.2, C18.2, H1.1, H2.1, H3.1, H4.1, J1.4, J1.8, J1.9, J2.4, J2.8, J2.9, J3.4, J3.5, J6.1, R1.2, R5.1, U1.1, U1.5, U1.6, U1.7, U1.8, U1.10, U1.16, U1.22, U1.25, U1.33, U1.37, U1.40, U1.42, U2.1
unnamed: R1.1, U1.28
unnamed: R2.2, U1.34
unnamed: R3.2, U1.36
unnamed: U1.11, Y1.1
unnamed: U1.12, Y1.2
OVER_CURRENT: R6.1, U1.48, U2.5
POWER_EN: U1.47, U2.4
VBUS: C3.1, C4.1, C5.1, C6.1, C8.1, C9.1, J1.1, J1.5, J2.1, J2.5, R4.2, U2.6, U2.7
VBUSM: R4.1, R5.2, U1.35
VD5: C7.1, C10.1, J6.2, U1.38, U2.2, U2.3
VD18: C2.1, C12.1, C14.1, C16.1, U1.3, U1.9, U1.26, U1.29
VD33: C1.1, C11.1, C13.1, C15.1, C17.1, C18.1, R2.1, R3.1, R6.2, U1.13, U1.19, U1.27, U1.32, U1.39, U1.41

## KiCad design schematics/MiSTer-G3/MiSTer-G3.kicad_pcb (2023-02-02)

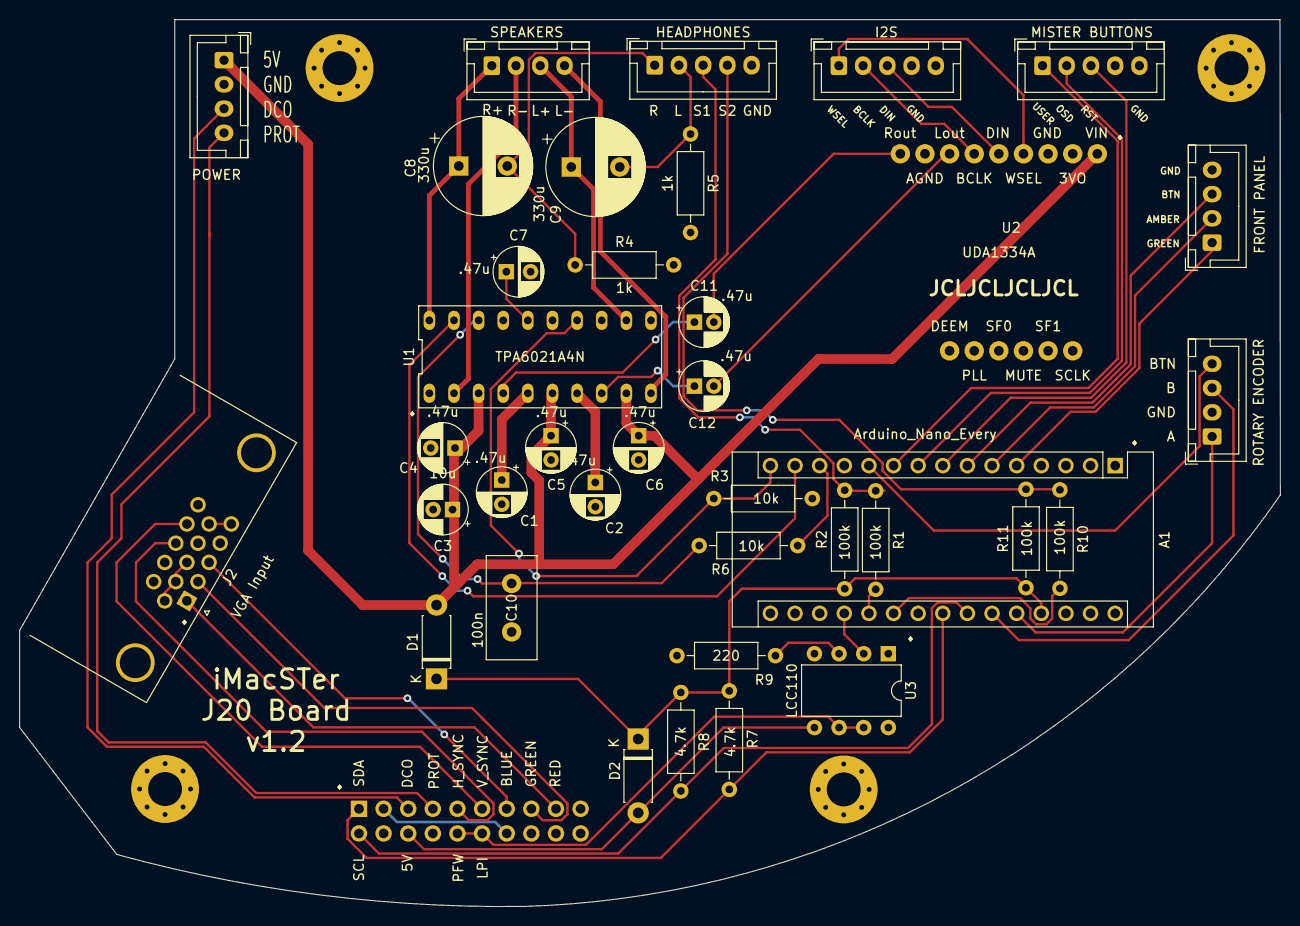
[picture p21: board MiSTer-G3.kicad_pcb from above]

Board: 2 copper layers, 130.0 x 91.5 mm, 42 parts (1 on the bottom side), 49 nets.

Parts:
A1: Arduino_Nano_Every; Arduino_Nano
C1, C2, C4, C5, C6, C7: .47u; CP_Radial_D5.0mm_P2.50mm
C3: 10u; CP_Radial_D5.0mm_P2.00mm
C8, C9: 330u; CP_Radial_D10.0mm_P5.00mm
C10: 100n; C_Disc_D10.5mm_W5.0mm_P5.00mm
C11, C12: .47u; CP_Radial_D5.0mm_P2.00mm
D1, D2: D_Schottky_ALT; D_DO-41_SOD81_P7.62mm_Horizontal
FRONT PANEL: Front Panel; JST_XH_B4B-XH-A_1x04_P2.50mm_Vertical
H1, H2, H3, H4: MountingHole_Pad; MountingHole_3.5mm_Pad_Via
HEADPHONES: Headphones; JST_XH_B5B-XH-A_1x05_P2.50mm_Vertical
J1: Apple J20; PinHeader_2x10_P2.54mm_Vertical
J2: VGA Input; DSUB-15-HD_Female_Horizontal_P2.29x1.98mm_EdgePinOffset8.35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
J4: I2S; JST_XH_B5B-XH-A_1x05_P2.50mm_Vertical
MISTER BUTTONS: Buttons; JST_XH_B5B-XH-A_1x05_P2.50mm_Vertical
POWER: Power; JST_XH_B4B-XH-A_1x04_P2.50mm_Vertical
R1, R2, R10, R11: 100k; R_Axial_DIN0207_L6.3mm_D2.5mm_P10.16mm_Horizontal
R3, R6: 10k; R_Axial_DIN0207_L6.3mm_D2.5mm_P10.16mm_Horizontal
R4, R5: 1k; R_Axial_DIN0207_L6.3mm_D2.5mm_P10.16mm_Horizontal
R7, R8: 4.7k; R_Axial_DIN0207_L6.3mm_D2.5mm_P10.16mm_Horizontal
R9: 220; R_Axial_DIN0207_L6.3mm_D2.5mm_P10.16mm_Horizontal
ROTARY ENCODER: Rotary Encoder; JST_XH_B4B-XH-A_1x04_P2.50mm_Vertical
SPEAKERS: Speaker; JST_XH_B4B-XH-A_1x04_P2.50mm_Vertical
U1: TPA6021A4N; TPA6021A4
U2: UDA1334A; UDA1334_Breakout
U3: LCC110; DIP-8_W7.62mm

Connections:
5V_MCU: A1.27, D1.1, D2.1, R2.1, R7.2, R8.1, R11.1
5V_PSU: C3.1, C4.1, C5.1, C6.1, D1.2, POWER.1, U1.3, U1.6, U1.9, U2.1
5V_TRICKLE: D2.2, J1.6, U3.5
AMBER_LED: A1.6, FRONT PANEL.2
AMP_ACTIVE: A1.15, R3.1, U1.14
AMP_SE: A1.14, U1.19
BLUE: J1.13, J2.3
BTN_OSD: A1.9, MISTER BUTTONS.2
BTN_RESET: A1.8, MISTER BUTTONS.3
BTN_USER: A1.10, MISTER BUTTONS.1
DCO: J1.5, POWER.3
GND: A1.4, A1.29, C1.2, C2.2, C3.2, C4.2, C5.2, C6.2, C7.2, C10.2, FRONT PANEL.4, H1.1, H2.1, H3.1, H4.1, HEADPHONES.5, J1.3, J1.4, J1.14, J1.16, J1.18, J1.20, J2.5, J2.6, J2.7, J2.8, J2.10, J4.4, MISTER BUTTONS.5, POWER.2, R3.2, R4.2, R5.2, R9.1, ROTARY ENCODER.2, U1.1, U1.11, U1.15, U1.17, U2.3, U2.8, U3.8
GREEN: J1.15, J2.2
GREEN_LED: A1.5, FRONT PANEL.1
H_SYNC: J1.9, J2.13
I2S_BCLK: J4.2, U2.6
I2S_DIN: J4.3, U2.5
I2S_WSEL: J4.1, U2.4
IVAD_SCL: A1.24, J1.2, R8.2
IVAD_SDA: A1.23, J1.1, R7.1
LHEAD: C9.2, HEADPHONES.2, R5.1
LIN: C12.2, U2.7
LPIACT: J1.10, J1.12, U3.6, U3.7
LSPKR+: C9.1, SPEAKERS.3, U1.12
LSPKR-: SPEAKERS.4, U1.10
unnamed: A1.13, R6.1
unnamed: C1.1, U1.5
unnamed: C2.1, U1.7
unnamed: C7.1, U1.16
unnamed: C11.1, U1.4
unnamed: C12.1, U1.8
unnamed: R9.2, U3.3
POWER_BTN: A1.7, FRONT PANEL.3
POWER_EN: A1.19, U3.2
PROT: J1.7, POWER.4
RED: J1.17, J2.1
RHEAD: C8.2, HEADPHONES.1, R4.1
RIN: C11.2, U2.9
ROT_A: A1.26, ROTARY ENCODER.1
ROT_B: A1.25, ROTARY ENCODER.3
ROT_BTN: A1.11, ROTARY ENCODER.4
RSPKR+: C8.1, SPEAKERS.1, U1.20
RSPKR-: SPEAKERS.2, U1.2
SHEAD1: HEADPHONES.3, R1.1, R2.2
SHEAD2: HEADPHONES.4, R10.1, R11.2
VOLUME: C10.1, R6.2, U1.18
V_SYNC: J1.11, J2.14
~HEAD_DETECT1: A1.20, R1.2
~HEAD_DETECT2: A1.21, R10.2

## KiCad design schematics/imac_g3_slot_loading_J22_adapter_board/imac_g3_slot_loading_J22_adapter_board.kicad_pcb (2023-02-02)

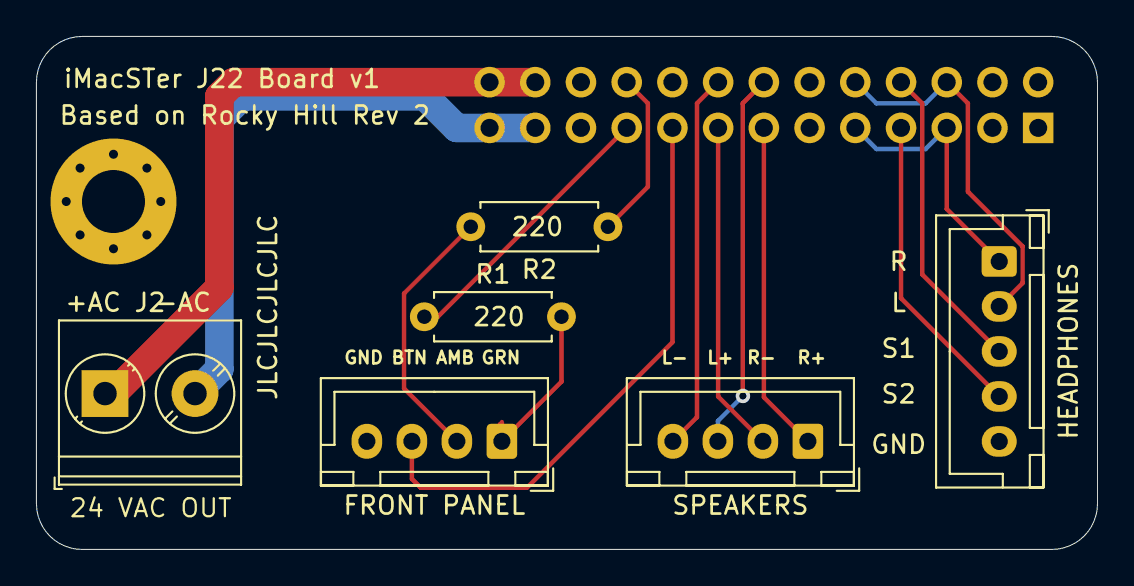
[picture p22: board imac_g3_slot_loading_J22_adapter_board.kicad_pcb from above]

Board: 2 copper layers, 58.9 x 28.5 mm, 8 parts (1 on the bottom side), 16 nets.

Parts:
FRONT PANEL: Conn_01x04_Male; JST_XH_B4B-XH-A_1x04_P2.50mm_Vertical
H1: MountingHole_Pad; MountingHole_3.5mm_Pad_Via
HEADPHONES: Conn_01x04_Male; JST_XH_B5B-XH-A_1x05_P2.50mm_Vertical
J1: Conn_02x13_Odd_Even; PinHeader_2x13_P2.54mm_Vertical
J2: AC Power; TerminalBlock_Phoenix_PT-1,5-2-5.0-H_1x02_P5.00mm_Horizontal
R1, R2: 220; R_Axial_DIN0207_L6.3mm_D2.5mm_P7.62mm_Horizontal
SPEAKERS: Conn_01x04_Male; JST_XH_B4B-XH-A_1x04_P2.50mm_Vertical

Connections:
/+AC: J1.24, J1.26, J2.1
/+AMBER_LED: J1.20, R2.1
/+GREEN_LED: J1.19, R1.1
/+LEFT_SPEAKER: J1.14, SPEAKERS.3
/+RIGHT_SPEAKER: J1.13, SPEAKERS.1
/-AC: J1.23, J1.25, J2.2
/-LEFT_SPEAKER: J1.16, SPEAKERS.4
/-RIGHT_SPEAKER: J1.15, SPEAKERS.2
/HEADPHONE_1_LEFT: HEADPHONES.2, J1.6, J1.10
/HEADPHONE_1_RIGHT: HEADPHONES.1, J1.5, J1.9
/HEADPHONE_1_SENSE: HEADPHONES.3, J1.8
/HEADPHONE_2_SENSE: HEADPHONES.4, J1.7
/POWER_BUTTON: FRONT PANEL.3, J1.17
GNDREF: FRONT PANEL.4, H1.1, HEADPHONES.5, J1.4, J1.11, J1.18
unnamed: FRONT PANEL.1, R1.2
unnamed: FRONT PANEL.2, R2.2

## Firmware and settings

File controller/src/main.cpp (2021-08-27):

#include <Arduino.h>
#include <Wire.h>

#include <SerialCommands.h>
#include <EEPROMWearLevel.h>
#include <Rotary.h>
#include <JC_Button.h>

#include "util.h"
#include "ivad.h"
#include "settings.h"

constexpr uint8_t kPinInRotaryA = A7;
constexpr uint8_t kPinInRotaryB = A6;
constexpr uint8_t kPinInRotaryButton = 8;
constexpr uint8_t kPinOutGreenLED = 2;
constexpr uint8_t kPinOutAmberLED = 3;
constexpr uint8_t kPinInPowerButton = 4;
constexpr uint8_t kPinOutMisterReset = 5;
constexpr uint8_t kPinOutMisterOSD = 6;
constexpr uint8_t kPinOutMisterUser = 7;


constexpr uint8_t kPinOutAmpActive = 12; // MISO
constexpr uint8_t kPinOutAmpSE = 11; // MOSI
constexpr uint8_t kPinOutVolume = 10;
constexpr uint8_t kPinOutSystemPower = A0;
constexpr uint8_t kPinInHeadDetect1 = A1;
constexpr uint8_t kPinInHeadDetect2 = A2;

enum class MisterButton
{
  Reset = 0,
  OSD = 1,
  User = 2
};

constexpr uint8_t kMisterButtons[3] = { kPinOutMisterReset, kPinOutMisterOSD, kPinOutMisterUser };

static unsigned long misterPressTime[3] = { 0, 0, 0 };

static char serial_command_buffer[32];
SerialCommands serial_commands(&Serial, serial_command_buffer, sizeof(serial_command_buffer), ";", " ");

static Rotary rotary(kPinInRotaryA, kPinInRotaryB);
static Button rotaryButton(kPinInRotaryButton);
static Button powerButton(kPinInPowerButton);

static Setting adjustmentSetting = Setting::Volume;

static bool systemOn = false;
static unsigned long lastSettingsStore = 0;

void System_TurnOn();
void System_TurnOff();
void System_HandlePowerButton();

void Mister_Press(MisterButton button);
void Mister_Update();

static void handler_on(SerialCommands *sender)
{
  System_TurnOn();
}
static SerialCommand cmd_on("on", handler_on);

static void handler_off(SerialCommands *sender)
{
  System_TurnOff();
}
static SerialCommand cmd_off("off", handler_off);

static void handler_status(SerialCommands *sender)
{
  Stream *s = sender->GetSerial();
  s->printf("Power is %s\n", systemOn ? "ON" : "OFF");
}
static SerialCommand cmd_status("status", handler_status);

static void handler_get(SerialCommands *sender)
{
  Stream *s = sender->GetSerial();
  const char *name = sender->Next();
  if (name == nullptr)
  {
    for (byte idx = 0; idx < (byte)Setting::Count; idx++)
    {
      Setting setting = (Setting)idx;
      s->printf("%s = %d\n", Settings_GetName(setting), Settings_Get(setting));
    }
  }
  else
  {
    byte value = Settings_GetByName(name);
    s->printf("%s = %d\n", name, value);
  }
}
static SerialCommand cmd_get("get", handler_get);

static void handler_set(SerialCommands *sender)
{
  Stream *s = sender->GetSerial();
  const char *name = sender->Next();
  const char *value = sender->Next();
  if (name == nullptr || value == nullptr)
  {
    s->println("Usage: set <name> <value>");
  }

  byte v = atoi(value);
  Settings_SetByName(name, v);
  Settings_Store();
  s->printf("%s = %d\n", name, Settings_GetByName(name));
}

static SerialCommand cmd_set("set", handler_set);

static void handler_adjust(SerialCommands *sender)
{
  Stream *s = sender->GetSerial();
  const char *name = sender->Next();
  if (name == nullptr)
  {
    s->println( "Resetting adjustment to VOLUME setting");
    adjustmentSetting = Setting::Volume;
    return;
  }

  Setting setting = Settings_GetSettingByName(name);
  if( setting == Setting::Count )
  {
    s->printf( "Unknown setting: %s\n", name);
    return;
  }

  adjustmentSetting = setting;
  s->printf( "Adjustment set to %s setting\n", Settings_GetName(setting));
}

static SerialCommand cmd_adjust("adjust", handler_adjust);

static void handler_init_video(SerialCommands *sender)
{
  IVAD_InitBoard();
}

static SerialCommand cmd_init_video("init_video", handler_init_video);

static void registerCommands()
{
  serial_commands.AddCommand(&cmd_status);
  serial_commands.AddCommand(&cmd_on);
  serial_commands.AddCommand(&cmd_off);
  serial_commands.AddCommand(&cmd_get);
  serial_commands.AddCommand(&cmd_set);
  serial_commands.AddCommand(&cmd_adjust);
  serial_commands.AddCommand(&cmd_init_video);
}

void setup()
{
  Serial.begin(9600);
  Wire.begin();

  rotary.begin(true);
  powerButton.begin();
  rotaryButton.begin();

  pinMode(kPinOutGreenLED, OUTPUT);
  digitalWrite(kPinOutGreenLED, LOW);

  pinMode(kPinOutAmberLED, OUTPUT);
  digitalWrite(kPinOutAmberLED, LOW);

  pinMode(kPinOutAmpActive, OUTPUT);
  digitalWrite(kPinOutAmpActive, LOW);

  pinMode(kPinOutSystemPower, OUTPUT);
  digitalWrite(kPinOutSystemPower, LOW);

  pinMode(kPinInHeadDetect1, INPUT);
  pinMode(kPinInHeadDetect2, INPUT);
  pinMode(kPinOutAmpSE, OUTPUT);
  digitalWrite(kPinOutAmpSE, HIGH);

  pinMode(kPinOutGreenLED, OUTPUT);
  digitalWrite(kPinOutGreenLED, LOW);

  pinMode(kPinOutAmberLED, OUTPUT);
  digitalWrite(kPinOutAmberLED, HIGH);

  analogWriteFrequency(32); // 32khz pwm
  pinMode(kPinOutVolume, OUTPUT);
  analogWrite(kPinOutVolume, 0);

  pinMode(kPinOutMisterOSD, INPUT);
  pinMode(kPinOutMisterReset, INPUT);
  pinMode(kPinOutMisterUser, INPUT);

  Settings_Init();
  registerCommands();
}

void loop()
{
  serial_commands.ReadSerial();
  rotaryButton.read();

  System_HandlePowerButton();

  Mister_Update();

  // Early out if we are powered down
  if( !systemOn )
  {
    return;
  }

  if( rotaryButton.wasPressed() )
  {
    Mister_Press(MisterButton::OSD);
  }

  const unsigned long now = millis();

  if( ( now - lastSettingsStore ) > 5000 ) {
    Settings_Store();
    lastSettingsStore = now;
  }

  if( digitalRead( kPinInHeadDetect1 ) || digitalRead( kPinInHeadDetect2 ) )
  {
    digitalWrite( kPinOutAmpSE, HIGH );
  }
  else
  {
    digitalWrite( kPinOutAmpSE, LOW );
  }

  const byte rotaryDir = rotary.process();
  if( rotaryDir != DIR_NONE )
  {
    if (rotaryDir == DIR_CW )
    {
      Settings_Set( adjustmentSetting, Settings_Get( adjustmentSetting ) - 1 );
    }
    else if (rotaryDir == DIR_CCW )
    {
      Settings_Set( adjustmentSetting, Settings_Get( adjustmentSetting ) + 1 );
    }

    DEBUG( "%s: %d\n", Settings_GetName( adjustmentSetting ), Settings_Get( adjustmentSetting ) );
  }

  // Adjust volume
  byte volume = Settings_Get( Setting::Volume );
  analogWrite( kPinOutVolume, volume );
}

void System_HandlePowerButton()
{
  static bool waitForRelease = false;
  static bool longPress = false;

  powerButton.read();

  if( waitForRelease )
  {
    waitForRelease = powerButton.isPressed();
    return;
  }

  if( systemOn )
  {
    if( powerButton.pressedFor(3000) )
    {
      System_TurnOff();
      waitForRelease = true;
    }
    else
    {
      if( powerButton.wasReleased() )
      {
        if( longPress )
        {
          Mister_Press(MisterButton::Reset);
        }
        else
        {
          Mister_Press(MisterButton::User);
        }
      }
    }
  }
  else
  {
    if( powerButton.wasPressed() )
    {
      System_TurnOn();
      waitForRelease = true;
    }
  }

  longPress = powerButton.pressedFor(500);
}

void System_TurnOn()
{
  DEBUG( "Power ON\n" );
  
  digitalWrite(kPinOutSystemPower, HIGH);
  digitalWrite(kPinOutGreenLED, HIGH);
  digitalWrite(kPinOutAmberLED, LOW);
  
  delay(250);
  
  IVAD_InitBoard();
  Settings_Apply();

  digitalWrite(kPinOutAmpActive, HIGH);

  systemOn = true;
}

void System_TurnOff()
{
  DEBUG( "Power OFF\n" );

  Settings_Store();

  digitalWrite(kPinOutGreenLED, LOW);
  digitalWrite(kPinOutAmberLED, HIGH);

  digitalWrite(kPinOutAmpActive, LOW);
  digitalWrite(kPinOutSystemPower, LOW);

  systemOn = false;
}

void Mister_Press(MisterButton button)
{
  DEBUG( "Mister Press: %d\n", button );
  int button_index = (int)button;
  misterPressTime[button_index] = millis();
  pinMode(kMisterButtons[button_index], OUTPUT);
}

void Mister_Update()
{
  unsigned long now = millis();

  for( int i = 0; i < 3; i++ )
  {
    if( misterPressTime[i] == 0 )
    {
      continue;
    }

    if( ( now - misterPressTime[i] ) > 50 )
    {
      DEBUG( "Mister Release: %d\n", i );
      misterPressTime[i] = 0;
      pinMode(kMisterButtons[i], INPUT);
    }
  }
}

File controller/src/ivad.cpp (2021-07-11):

#include <Wire.h>

static void writeToIvad(byte address, byte message)
{
  Wire.beginTransmission(address);
  Wire.write(message);
  Wire.endTransmission();
}

static void writeToIvad(byte address, byte message1, byte message2)
{
  Wire.beginTransmission(address);
  Wire.write(message1);
  Wire.write(message2);
  Wire.endTransmission();
}

static void readFromIvad(byte address, byte bytes)
{
  char buf[bytes + 1];
  byte bytesRead = 0;
  Wire.requestFrom(address, bytes);
  while (Wire.available())
  {
    char c = Wire.read();
    buf[bytesRead++] = c;
  }
  buf[bytesRead] = '\0';
}

void IVAD_InitBoard()
{
  writeToIvad(0x46, 0x13, 0x00);
  writeToIvad(0x46, 0x13, 0x00);
  readFromIvad(0x46, 1);
  writeToIvad(0x46, 0x09, 0x00);
  writeToIvad(0x53, 0x33);
  readFromIvad(0x53, 1);
  writeToIvad(0x46, 0x13, 0x0b);
  writeToIvad(0x46, 0x00, 0x00);
  writeToIvad(0x46, 0x08, 0xe4);
  writeToIvad(0x46, 0x12, 0xc9);
  writeToIvad(0x53, 0x00);
  readFromIvad(0x53, 10);
  writeToIvad(0x53, 0x0a);
  readFromIvad(0x53, 10);
  writeToIvad(0x53, 0x14);
  readFromIvad(0x53, 10);
  writeToIvad(0x53, 0x1e);
  readFromIvad(0x53, 10);
  writeToIvad(0x53, 0x28);
  readFromIvad(0x53, 10);
  writeToIvad(0x53, 0x32);
  readFromIvad(0x53, 10);
  writeToIvad(0x53, 0x3c);
  readFromIvad(0x53, 10);
  writeToIvad(0x53, 0x46);
  readFromIvad(0x53, 10);
  writeToIvad(0x53, 0x50);
  readFromIvad(0x53, 10);
  writeToIvad(0x53, 0x5a);
  readFromIvad(0x53, 10);
  writeToIvad(0x46, 0x01, 0x82);
  writeToIvad(0x46, 0x02, 0x82);
  writeToIvad(0x46, 0x03, 0x82);
  writeToIvad(0x46, 0x04, 0xa0);
  writeToIvad(0x46, 0x05, 0xa0);
  writeToIvad(0x46, 0x06, 0xa0);
  writeToIvad(0x46, 0x07, 0xad);
  writeToIvad(0x46, 0x08, 0xe4);
  writeToIvad(0x46, 0x09, 0x3d);
  writeToIvad(0x46, 0x0a, 0x9e);
  writeToIvad(0x46, 0x0b, 0xb4);
  writeToIvad(0x46, 0x0c, 0xc4);
  writeToIvad(0x46, 0x0d, 0x27);
  writeToIvad(0x46, 0x0e, 0xbf);
  writeToIvad(0x46, 0x0f, 0xc0);
  writeToIvad(0x46, 0x10, 0x40);
  writeToIvad(0x46, 0x11, 0x0a);
  writeToIvad(0x46, 0x12, 0x5b);
  writeToIvad(0x46, 0x00, 0xff);
  writeToIvad(0x53, 0x00);
  readFromIvad(0x53, 10);
  writeToIvad(0x53, 0x10);
  readFromIvad(0x53, 10);
  writeToIvad(0x53, 0x20);
  readFromIvad(0x53, 10);
  writeToIvad(0x53, 0x30);
  readFromIvad(0x53, 10);
  writeToIvad(0x46, 0x11, 0x05);
  writeToIvad(0x46, 0x00, 0xff);
  writeToIvad(0x46, 0x00, 0x00);
  writeToIvad(0x46, 0x07, 0xb1);
  writeToIvad(0x46, 0x0d, 0x10);
  writeToIvad(0x46, 0x0c, 0xc7);
  writeToIvad(0x46, 0x09, 0x4a);
  writeToIvad(0x46, 0x08, 0xea);
  writeToIvad(0x46, 0x0f, 0xc0);
  writeToIvad(0x46, 0x0b, 0xae);
  writeToIvad(0x46, 0x12, 0x5b);
  writeToIvad(0x46, 0x00, 0xff);
  writeToIvad(0x46, 0x11, 0x05);
  writeToIvad(0x46, 0x00, 0xff);
  writeToIvad(0x46, 0x10, 0x40);
  writeToIvad(0x46, 0x06, 0xa0);
  writeToIvad(0x46, 0x05, 0xa0);
  writeToIvad(0x46, 0x04, 0xa0);
  writeToIvad(0x46, 0x03, 0x82);
  writeToIvad(0x46, 0x02, 0x82);
  writeToIvad(0x46, 0x01, 0x82);
  writeToIvad(0x46, 0x11, 0x05);
  writeToIvad(0x46, 0x00, 0xff);
  writeToIvad(0x46, 0x11, 0x05);
  writeToIvad(0x46, 0x00, 0xff);
  writeToIvad(0x46, 0x10, 0x40);
  writeToIvad(0x46, 0x06, 0xa0);
  writeToIvad(0x46, 0x05, 0xa0);
  writeToIvad(0x46, 0x04, 0xa0);
  writeToIvad(0x46, 0x03, 0x82);
  writeToIvad(0x46, 0x02, 0x82);
  writeToIvad(0x46, 0x01, 0x82);
  writeToIvad(0x46, 0x11, 0x05);
  writeToIvad(0x46, 0x00, 0xff);
}

void IVAD_SetParameter(byte index, byte value)
{
  writeToIvad(0x46, index, value);
}

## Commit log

2021-07-14 Headers and routing
    Added JST header for mister buttons
    Split screw terminals into separate JST headers for speakers, headphones and front panel.
    Added rotary encoder button
    Re-routed pcb
    [MiSTer-G3.kicad_pcb, MiSTer-G3.sch]
2021-07-17 Fixed up USBHub symbol and footprint library
    [USBHub.kicad_pcb, USBHub.sch]
2021-07-21 Schematic changes
    Reworked Rocky Hills j22 adaptor, removed microphone, added JST headers for speakers, buttons and headphones.
    Updated USBHub for FE1.1 5V doesn't go through the current limiting switch
    [USBHub.kicad_pcb, USBHub.sch, imac_g3_slot_loading_J22_adapter_board.kicad_pcb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]
2021-07-25 Headphone sense
    Added second sense wire from j22 board since they can't be combined.
    Send sense inputs to arduino and control SE/~BTL signal from there. This will allow different volume settings for each mode.
    Re-route.
    Fix silkscreen labels
    [MiSTer-G3.kicad_pcb, MiSTer-G3.sch, imac_g3_slot_loading_J22_adapter_board.kicad_pcb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]
2021-08-15 Code and schematic changes
    Fixed incorrect routing for decoupling caps
    Updated code to handle headphones, power button and mister buttons.
    [MiSTer-G3-alt.kicad_pcb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]
2021-08-16 USBHub
    Added 3d models for usb connectors
    Exported a 3d model for the whole hub
    Changed the power connector to a horizontal one, not sure if that's what I'll use yet.
    [61400826021.stp, USB-type-B.stp, USBHub.kicad_pcb]
2021-08-27 Added 3d printing models
    [iMacSTer IO Shield.stl, iMacSTer Mount.stl, iMacSTer Volume Knob.stl]
2023-02-02 Gerber Files
    Exported gerber files for all PCBs
    Updated main board to version 1.2 with fixes the routing that were bodged into previous version.
    Updated to kicad 6
    [MiSTer-G3-B_Cu.gbr, MiSTer-G3-B_Mask.gbr, MiSTer-G3-Edge_Cuts.gbr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]
2023-02-23 Update part numbers
    [USBHub.kicad_sch, imac_g3_slot_loading_J22_adapter_board.kicad_sch]
2023-02-23 Added missing csv files
    [MiSTer-G3.csv, USBHub.csv, imac_g3_slot_loading_J22_adapter_board.csv]
